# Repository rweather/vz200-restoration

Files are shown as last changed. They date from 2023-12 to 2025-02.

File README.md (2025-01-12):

VZ200 Restoration
=================

This repository chronicles my exploits in restoring a Dick Smith VZ200
that I got off eBay.  The VZ200 is a rebadged VTech Laser 200, which was
sold in Australia from 1983 onwards.

The eBay seller Ben had this to say about the unit: "It was an op-shop
pickup from my Nan and had been in storage in a plastic container for who
knows how long.  As it did not have any leads I never tested it."

## Technical specifications

* Z80A 8-bit CPU, running at 3.58MHz.
* 16K of ROM containing BASIC.
* 2K of video RAM for either 32 x 16 text mode or 128 x 64 graphics mode.
* 6K of user program RAM, expandable to 22K using a 16K RAM expansion module.
* 45 key chiclet keyboard organized in a 6x8 matrix.
* Motorola 6847 video processor.
* RF and composite video output.

Note: The VZ300 is essentially the same computer except that it has 16K of
user program RAM on-board and a mechanical keyboard.

Outside of Australia and New Zealand, the VZ200 and VZ300 were known as the
Laser 200 and Laser 310 respectively.

## Updates

Since doing the original restoration, I was gifted some more VZ200/VZ300
gear from a friend at work, Brian.  Brian got these years ago from an old
fellow in the local amateur radio network who was obviously a big fan of the
VZ computers, but was getting too old to work on them.

Many of the pieces have custom modifications and may or may not work.
Brian had 2 or 3 of everything.  He gave me these and kept the rest:

* Set of joysticks (working, just needed a clean).
* Printer interface.
* [16K memory expansion module that has been modified to 32K](Memory_Expansion_32K.md)
* Data casette recorder.
* Floppy disk controller and floppy disk drive.  Plus some floppy disks.
  Drive almost works but has a head crash; needs head re-alignment.
* Serial port kit.
* [Two VZ300's that were not working, but one now is.](VZ300_Restoration.md)

The links point at information about the restoration on each item.

Brian also gifted me a Microbee kit (assembled), two TRS-80 color computers,
and a TRS-80 printer/plotter.

I will gradually work on restoring these and post the results as I go.

And now onto the original restoration ...

## Restoration

Note: All images below have been scaled down.  Use "Open Image in New Tab"
or equivalent in your Web browser for a full-sized image.

### Initial condition of the unit

There were no power or video cables with the unit that was shipped to me.
The unit had not been powered on for a long time.  The power input is 9V DC
with a standard DC barrel jack, so power can be easily supplied with a
modern plugpack / wall wart.

The outside of the case was dirty, but nothing that some water, Windex,
paper towels, and elbow grease wouldn't fix.  The plastic was a little
yellowed but not too bad.

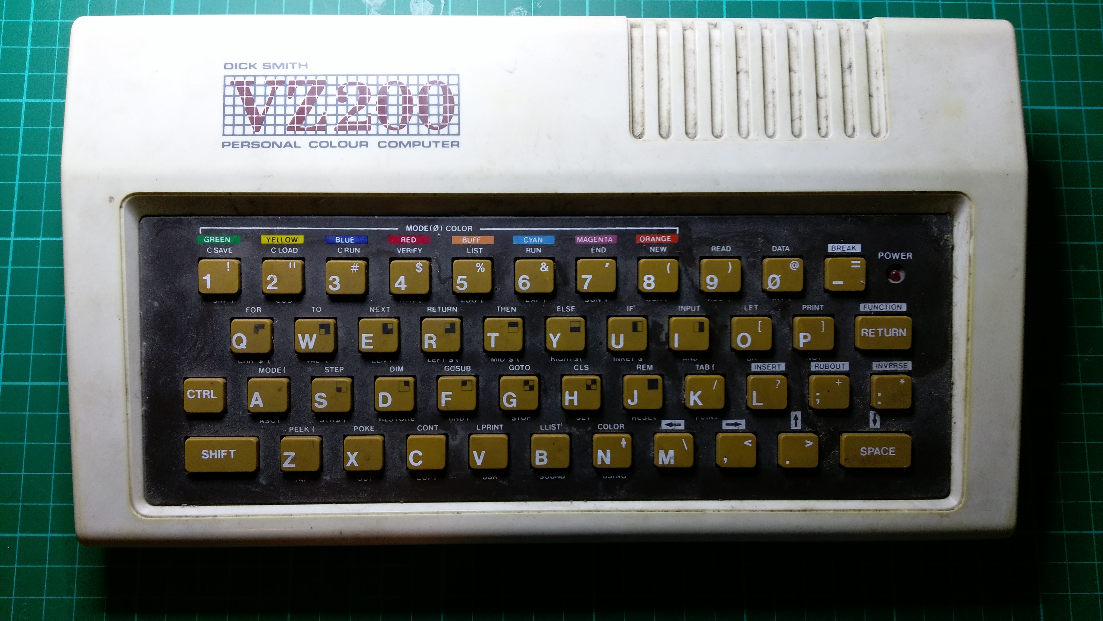
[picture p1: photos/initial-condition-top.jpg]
Initial Condition Top


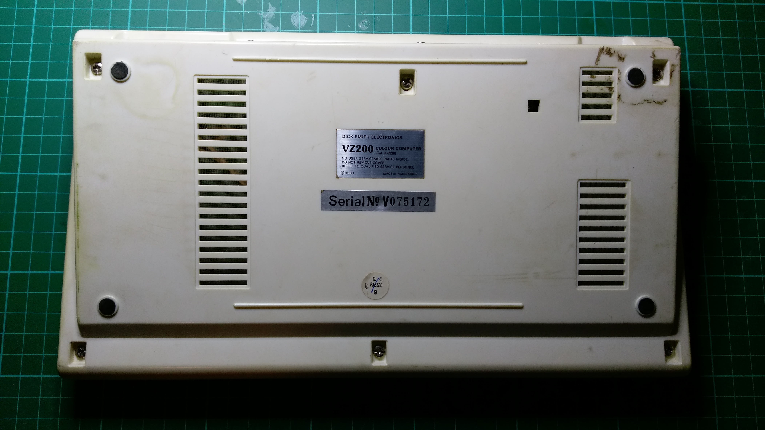
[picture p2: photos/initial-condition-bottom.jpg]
Initial Condition Bottom


Serial number 075172.

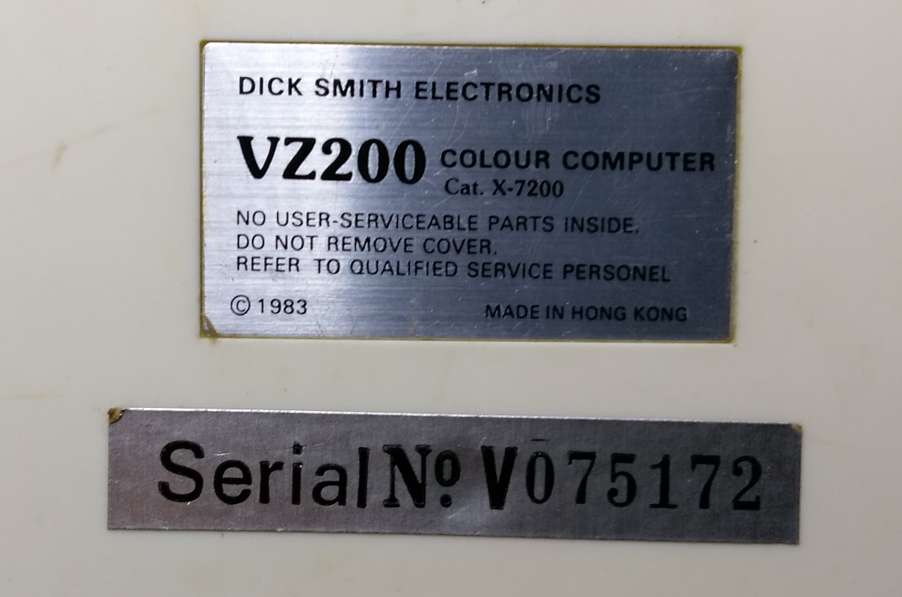
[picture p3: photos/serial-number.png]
Serial Number


The covers for the memory expansion and peripheral ports were still in place,
so I was hopeful that it had never been opened.

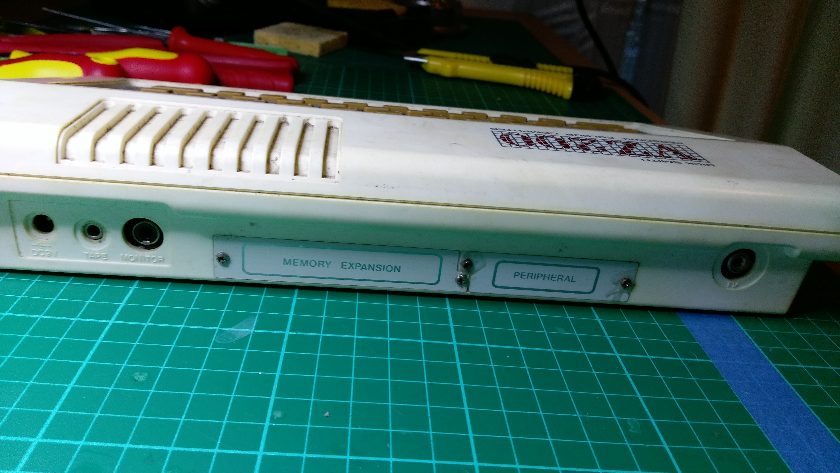
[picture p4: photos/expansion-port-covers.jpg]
Expansion Port Covers


However, once inside I discovered some dirt and the braids connecting the
RF shield to ground had been cut:

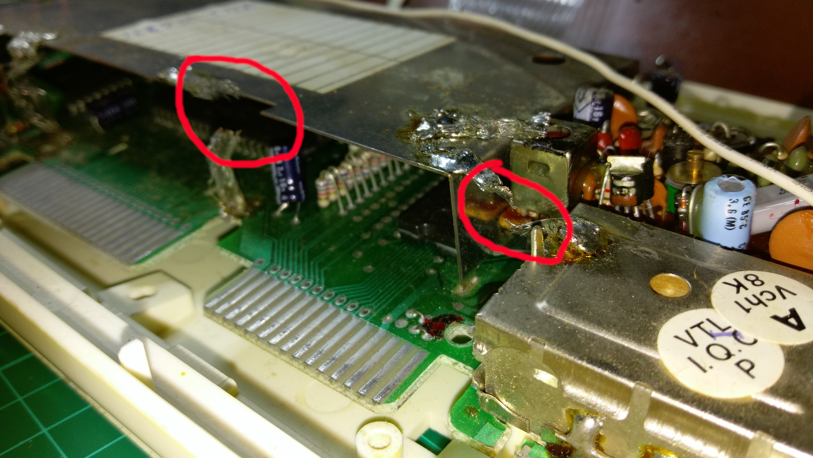
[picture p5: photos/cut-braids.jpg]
Cut Braids


It looks like someone had tried to remove the RF shield before and had
not succeeded.  The shield is soldered down to the motherboard, but some
of the legs were loose indicating partial success.

### Checking rail-to-rail resistance

I measured the resistance between 5V and ground - 284 ohms.  The same
between 9V and ground.  Probably OK.  Not a dead short anyway.

The resistance between 5V and 9V was 34 ohms, due to an actual 32 ohm
resistor between the two:

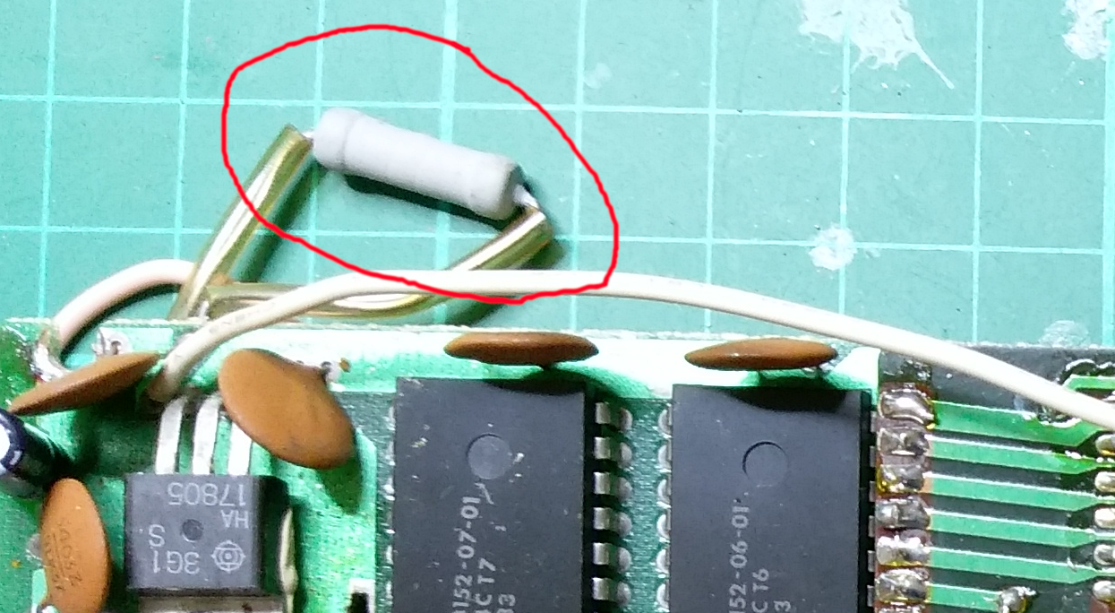
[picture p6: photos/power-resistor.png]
Power Resistor


### Removing the keyboard

I had to remove the keyboard from the top half of the case to clean the
case properly.  It looks like the original keyboard was in a module that
was pushed in from the top and then snapped into place.  Removing the
screws was easy, but I couldn't slide out the keyboard PCB without
cutting the snaps or the cross-piece.  I elected to cut the cross-piece:

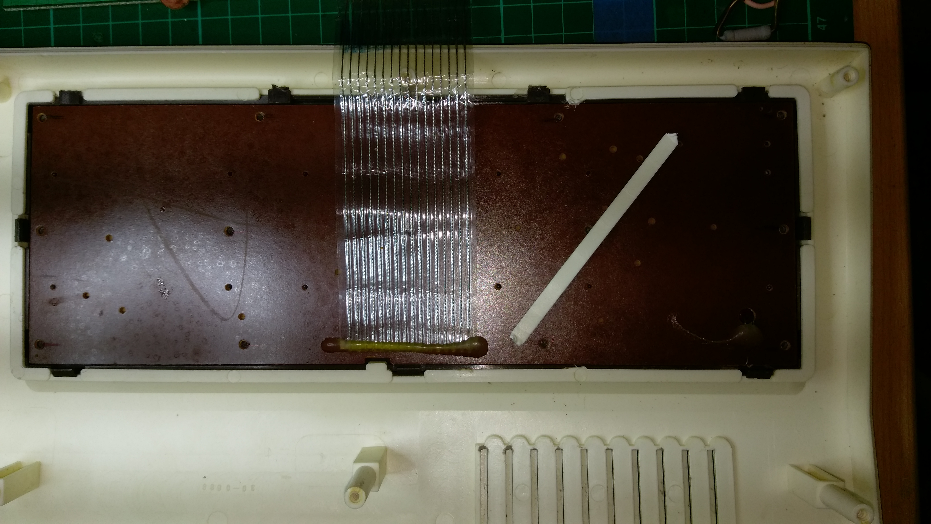
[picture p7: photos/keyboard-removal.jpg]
Keyboard Removal


The keyboard PCB has scratched-on letters indicating which key is which.
That's useful.

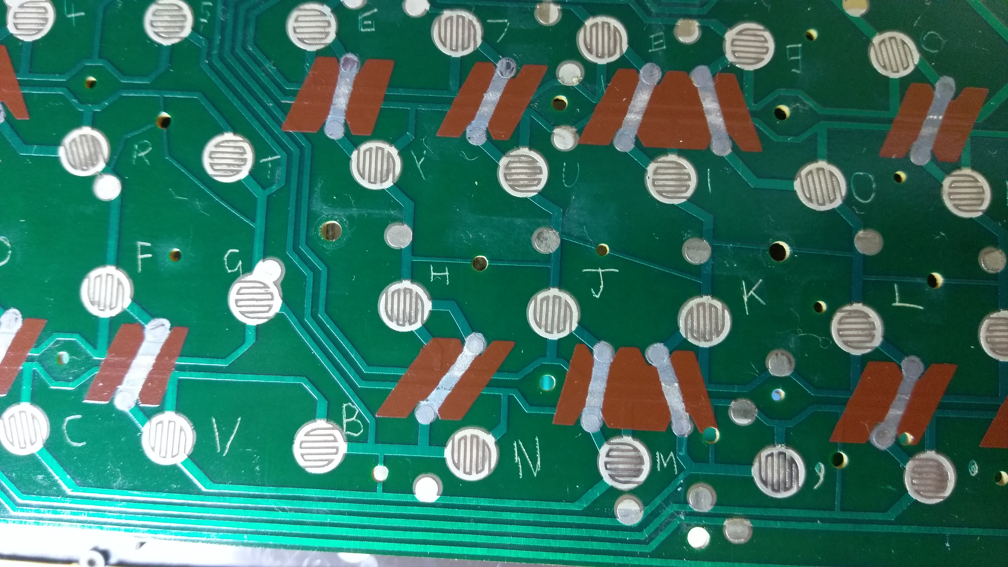
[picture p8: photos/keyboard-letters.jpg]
Keyboard Letters


After that, it was easy to remove the rubber membrane for cleaning.
The key caps themselves are molded into the membrane, so there are no
individual keys to get lost.  The membrane was filthy:

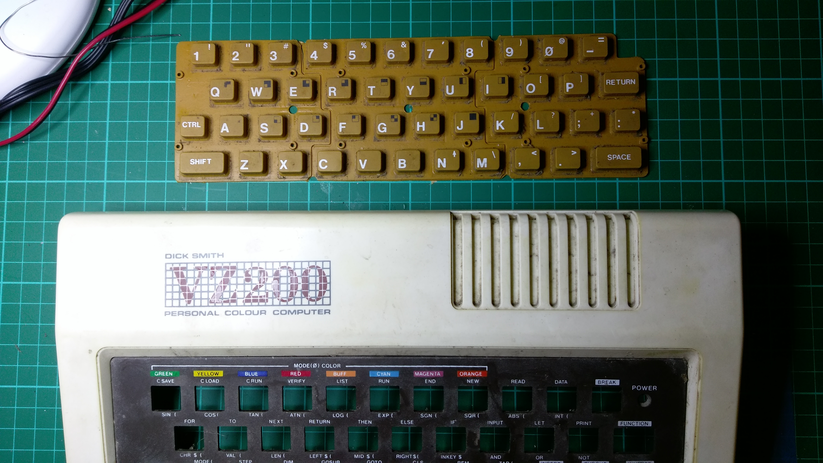
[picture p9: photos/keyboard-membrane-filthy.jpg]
Keyboard Membrane Before Cleaning


### Removing the RF shield

The person who tried to remove the RF shield didn't do a very good job.
Solder had bridged tracks, and one of the tracks was ripped right off the PCB:

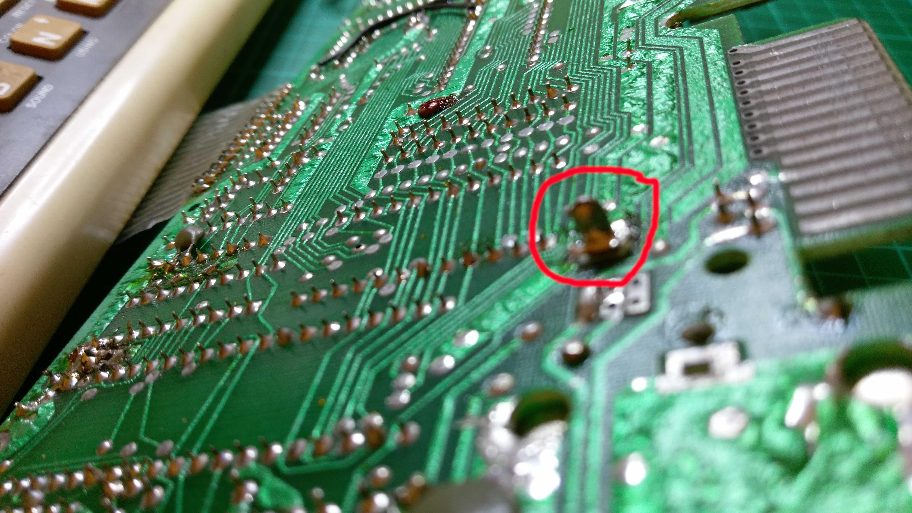
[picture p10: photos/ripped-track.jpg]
Ripped Track


Using a solder sucker, solder wick, flux, heat, and some patience,
I managed to clean up the excess solder and get the shield off:

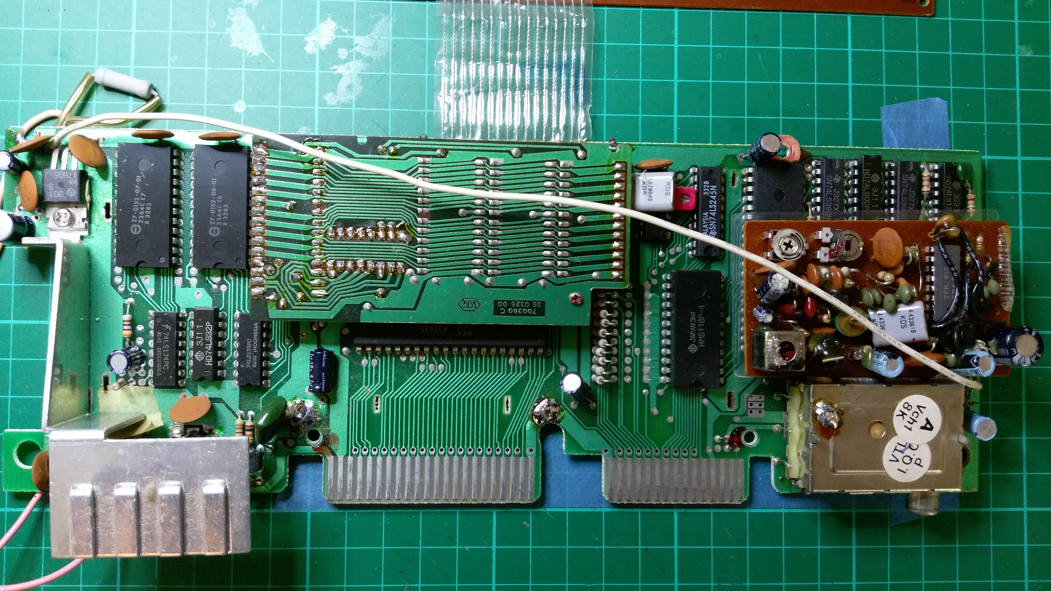
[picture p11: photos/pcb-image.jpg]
PCB Image


Here is the same photo with the major components marked up:

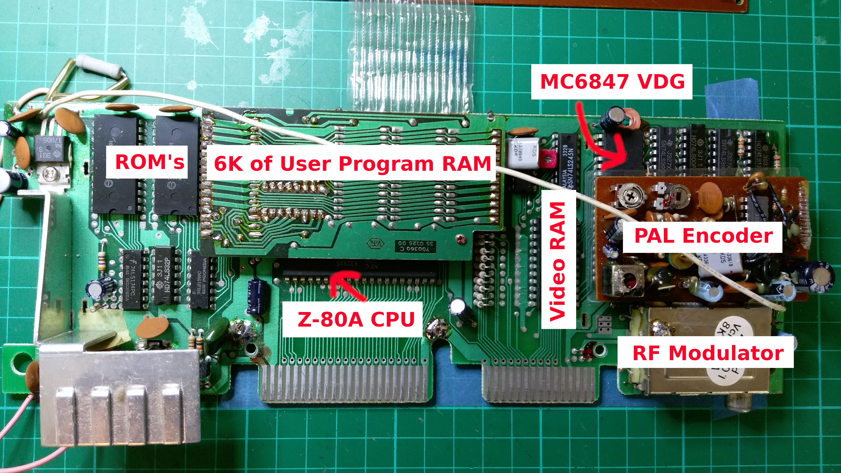
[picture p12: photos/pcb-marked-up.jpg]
PCB Image With Markings


And here is a diagram that shows the location of all IC's, looking forward
from the front of the PCB (not to scale):

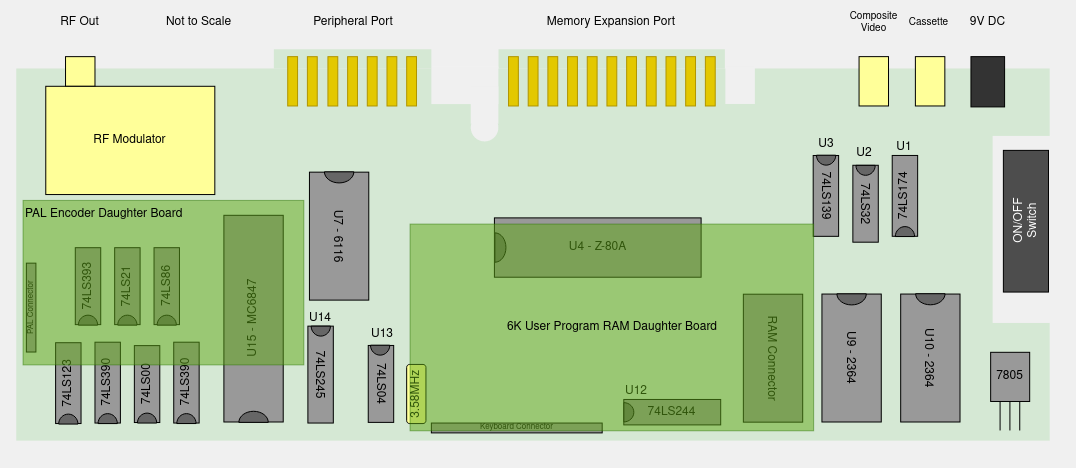
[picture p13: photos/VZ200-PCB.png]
PCB Layout


### Cleaning the case and keyboard membrane

I cleaned the top and bottom of the case and the keyboard membrane
with Windex and water.  Some stubborn stains on the back were cleaned
off with isopropyl alchohol.

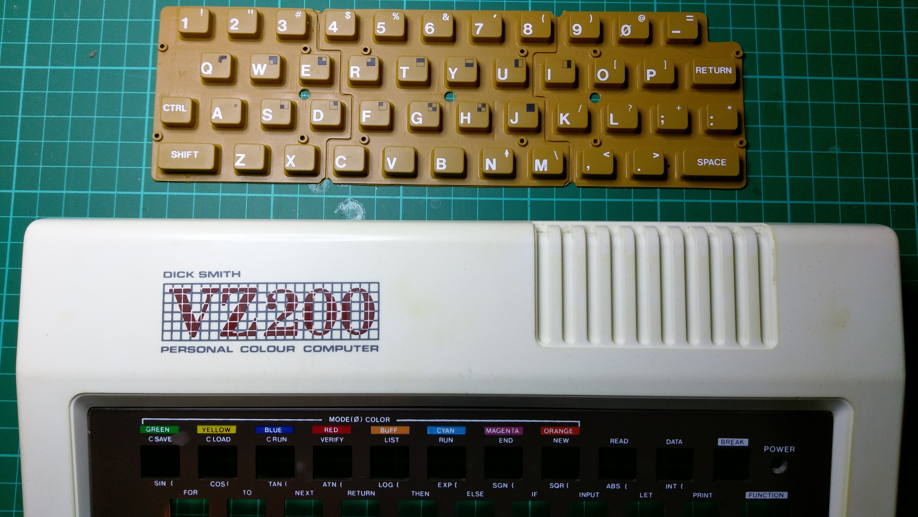
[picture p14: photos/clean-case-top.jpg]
Top and Keyboard Membrane After Cleaning


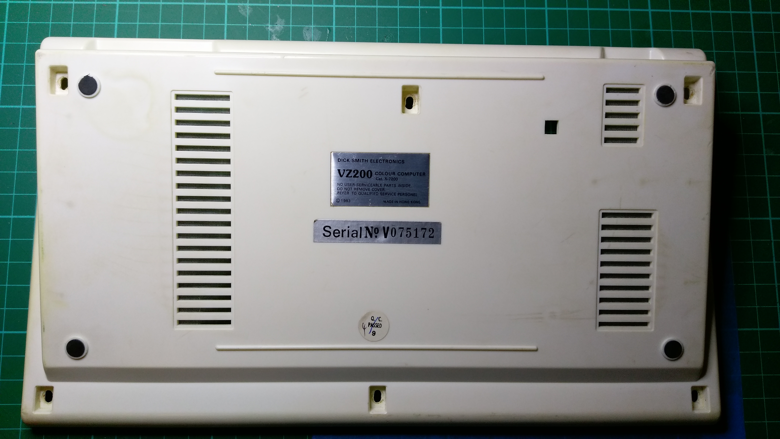
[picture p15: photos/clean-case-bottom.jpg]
Bottom After Cleaning


### First power on test

I connected a current-limited bench power supply set to 9V and 1A and
gingerly turned it on.  The 7805 voltage regulator was putting out 4.925V
and the system was consuming 650mA from the 9V supply.  So it looks like
no dead shorts on the board.

No blue smoke escaped, and the power LED turned on, so that's good.

### Checking signals

I checked the signals coming out of the CPU.  The clock on pin 6
was sitting at 3.57797MHz - close enough to 3.58MHz.

The address lines and most data lines had reasonable looking activity,
but D1, D2, and D6 had weird-looking signals like this for D6:

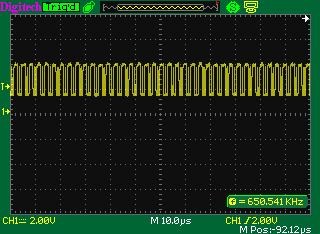
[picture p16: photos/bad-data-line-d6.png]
Bad D6 Line


The base line of the signal is shifted up by about 1.7V.  D1 and D2 were
also shifted to half-way between 0V and 5V.  So there was a conflict
on the data bus somewhere.

### Video test

Connecting up a Composite-to-HDMI video converter, I got garbage on
the screen.  Powering on and off multiple times gives different garbage
each time:

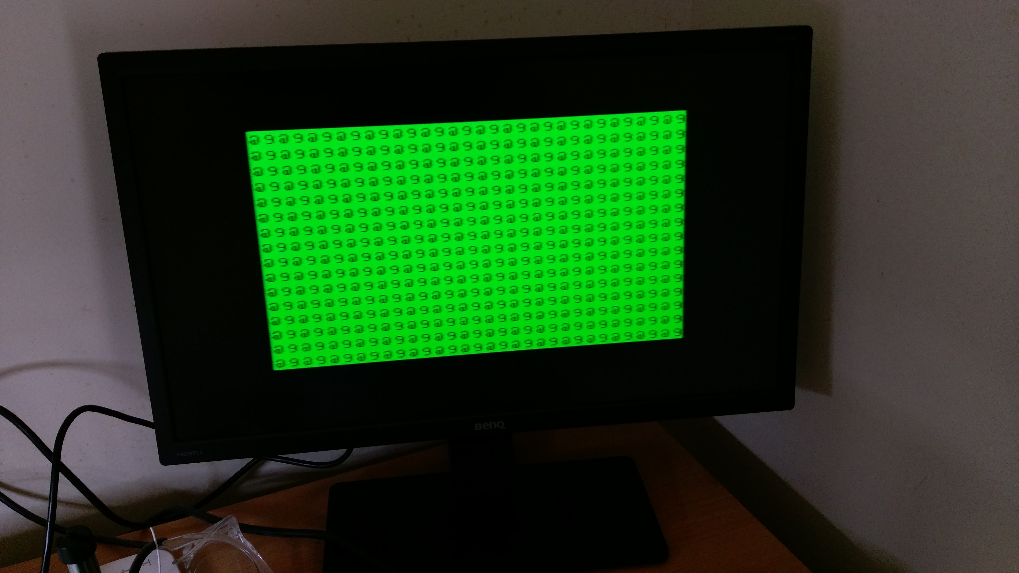
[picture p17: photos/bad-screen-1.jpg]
Bad Screen 1


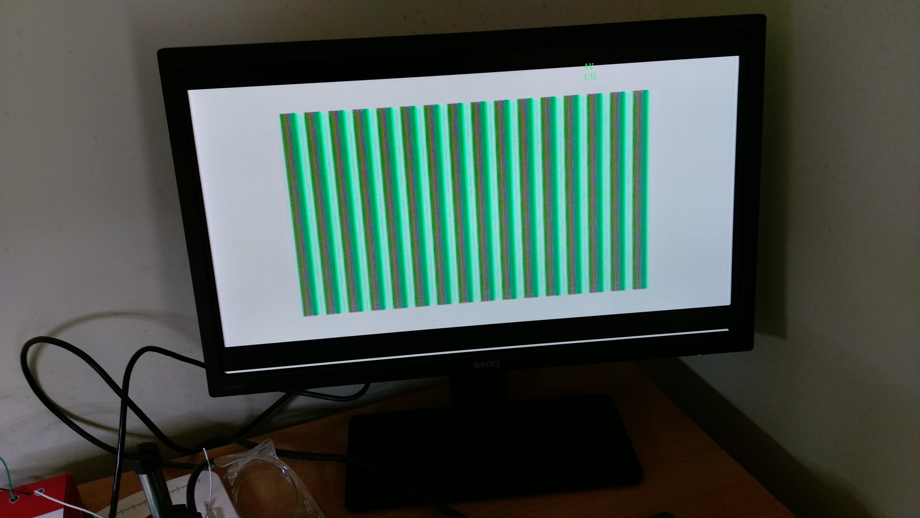
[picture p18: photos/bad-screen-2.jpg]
Bad Screen 2


The video clock into the MC6847 was around 3MHz, the "HS" horizontal sync
signal out was around 13kHz, and the "FS" frame sync signal out was 50Hz.

The video clock should be 3.58MHz.  However, the schematic gates the
main 3.58MHz system clock to generate the video clock.  "CLK" is the
main system clock:

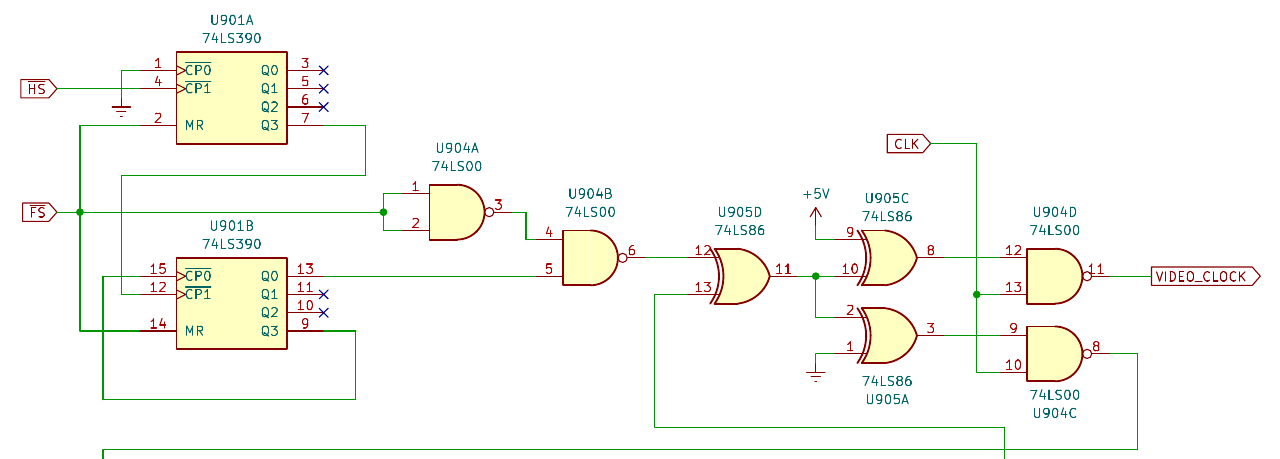
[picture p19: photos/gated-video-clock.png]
Gated Video Clock


In some parts of the frame during the horizontal and vertical sync times,
the video clock is disabled.  I think my oscilloscope was getting confused
and showing the average clock rate which undercounts due to the gating.
The same applies to the horizontal sync signal which isn't active for the
entire frame.

The frame sync was bang on 50Hz, and the generated video looked reasonable,
so the MC6847 must be getting the right timing.

The pictures don't show it, but there was a lot of static on the screen
which may be due to the clock signals, the CPU struggling to write to
video RAM, or a noisy component in the video output circuitry.

### Replacing the ROM's

From information I gleaned online, a common cause of bus crashes on the
VZ200 are the 2364 mask ROM's U9 and U10.  In [this video](https://www.youtube.com/watch?v=YIOjtE3j2aw)
from Tommy Ovesen at [Arctic Retro](https://www.arcticretro.com/),
he had similar screen corruption to my case.

Tommy replaced almost all the chips on the board before replacing the ROM's.
The ROM's were the ultimate culprit.  Rather than try replacing bus
transceivers, the CPU, or the video chip, I decided to learn from Tommy's
excellent work and start with the ROM's.

The wrinkle is that the original ROM's are 24-pin 2364's, but the best
replacements would be 28-pin 2764 EPROM's or (even better) AT28C64 EEPROM's.

It turns out that the PCB actually prefers 28-pin EPROM's!  There are
extra pin holes for the 28-pin footprint:

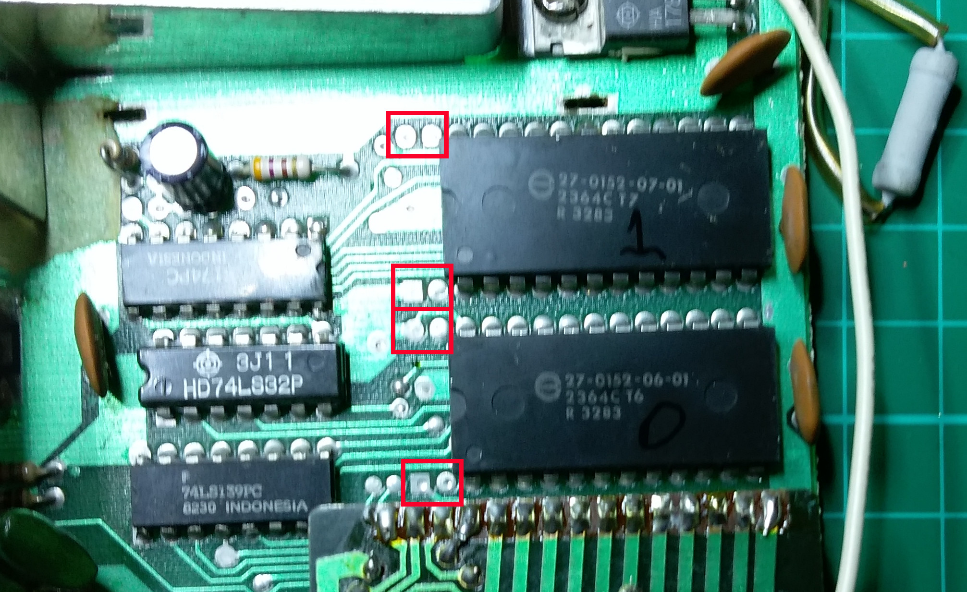
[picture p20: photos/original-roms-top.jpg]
Original ROM's Top


And on the back there are bodge wires to remap the 28-pin footprint into
24-pin so that the 2364's can be fitted:

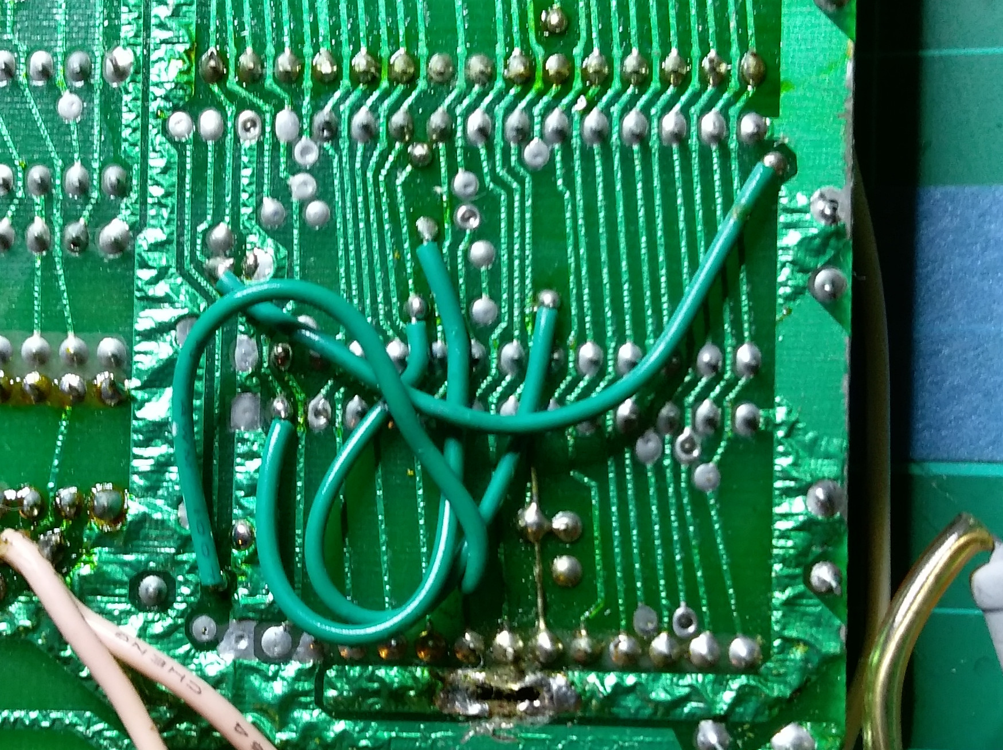
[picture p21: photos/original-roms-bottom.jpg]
Original ROM's Bottom


If we look at the original schematic in the
[VZ200 Technical Reference Manual](http://www.vz200.org/bushy/VZ200_technical_reference_manual.pdf), we can see that the footprint was supposed to be 28-pin:

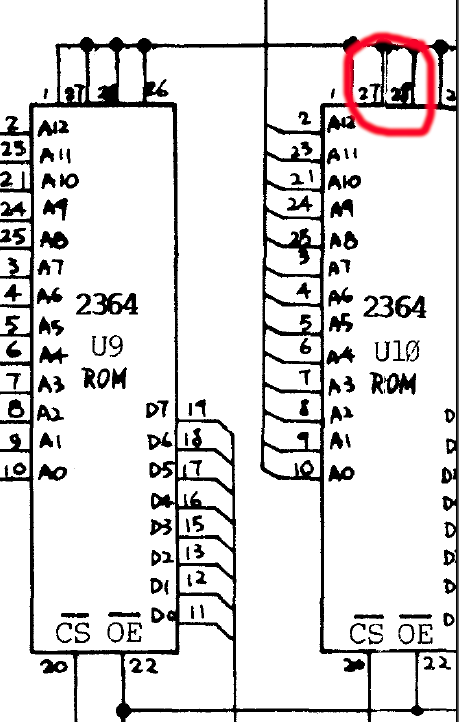
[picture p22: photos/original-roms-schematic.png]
ROM Schematic


My guess is that the manufacturer originally intended to use 28-pin
2764 EPROM's, but to save cost they went with 24-pin 2364's instead.
Apparently it was cheaper to pay people to modify thousands of PCB's
with bodge wires than to re-spin the PCB.

This was good for me.  I removed the ROM's and the bodge wires, and then
re-bodged the PCB back to the 28-pin footprint for the two AT28C64B-15PU
EEPROM's that I purchased from Mouser.  The following table shows the pin
mapping between the 24-pin and 28-pin footprints, with the major changes
shown in bold:

<table border="1">
<tr><td><b>2364 Pin</b></td><td><b>Connection</b></td><td><b>AT28C64 Pin</b></td><td><b>Connection</b></td></tr>
<tr><td> </td><td> </td><td><b>1</b></td><td><b>5V</b></td></tr>
<tr><td> </td><td> </td><td><b>2</b></td><td><b>A12</b></td></tr>
<tr><td>1</td><td>A7</td><td>3</td><td>A7</td></tr>
<tr><td>2</td><td>A6</td><td>4</td><td>A6</td></tr>
<tr><td>3</td><td>A5</td><td>5</td><td>A5</td></tr>
<tr><td>4</td><td>A4</td><td>6</td><td>A4</td></tr>
<tr><td>5</td><td>A3</td><td>7</td><td>A3</td></tr>
<tr><td>6</td><td>A2</td><td>8</td><td>A2</td></tr>
<tr><td>7</td><td>A1</td><td>9</td><td>A1</td></tr>
<tr><td>8</td><td>A0</td><td>10</td><td>A0</td></tr>
<tr><td>9</td><td>D0</td><td>11</td><td>D0</td></tr>
<tr><td>10</td><td>D1</td><td>12</td><td>D1</td></tr>
<tr><td>11</td><td>D2</td><td>13</td><td>D2</td></tr>
<tr><td>12</td><td>GND</td><td>14</td><td>GND</td></tr>
<tr><td>13</td><td>D3</td><td>15</td><td>D3</td></tr>
<tr><td>14</td><td>D4</td><td>16</td><td>D4</td></tr>
<tr><td>15</td><td>D5</td><td>17</td><td>D5</td></tr>
<tr><td>16</td><td>D6</td><td>18</td><td>D6</td></tr>
<tr><td>17</td><td>D7</td><td>19</td><td>D7</td></tr>
<tr><td><b>18</b></td><td><b>A11</b></td><td><b>20</b></td><td><b>CE</b></td></tr>
<tr><td>19</td><td>A10</td><td>21</td><td>A10</td></tr>
<tr><td><b>20</b></td><td><b>CE</b></td><td><b>22</b></td><td><b>RD</b></td></tr>
<tr><td><b>21</b></td><td><b>A12</b></td><td><b>23</b></td><td><b>A11</b></td></tr>
<tr><td>22</td><td>A9</td><td>24</td><td>A9</td></tr>
<tr><td>23</td><td>A8</td><td>25</td><td>A8</td></tr>
<tr><td>24</td><td>5V</td><td>26</td><td>5V</td></tr>
<tr><td> </td><td> </td><td><b>27</b></td><td><b>5V</b></td></tr>
<tr><td> </td><td> </td><td><b>28</b></td><td><b>5V</b></td></tr>
</table>

<b>Note:</b> The chip enable "CE" pins for the two ROM's are connected
to different pins on U3 / 74LS139.  CE on U9 / ROM0 should be connected
to pin 4 on U3.  CE on U10 / ROM1 should be connected to pin 5 on U3.
All other pins are connected identically on both ROM's.

Here is the PCB with the new ROM's fitted:

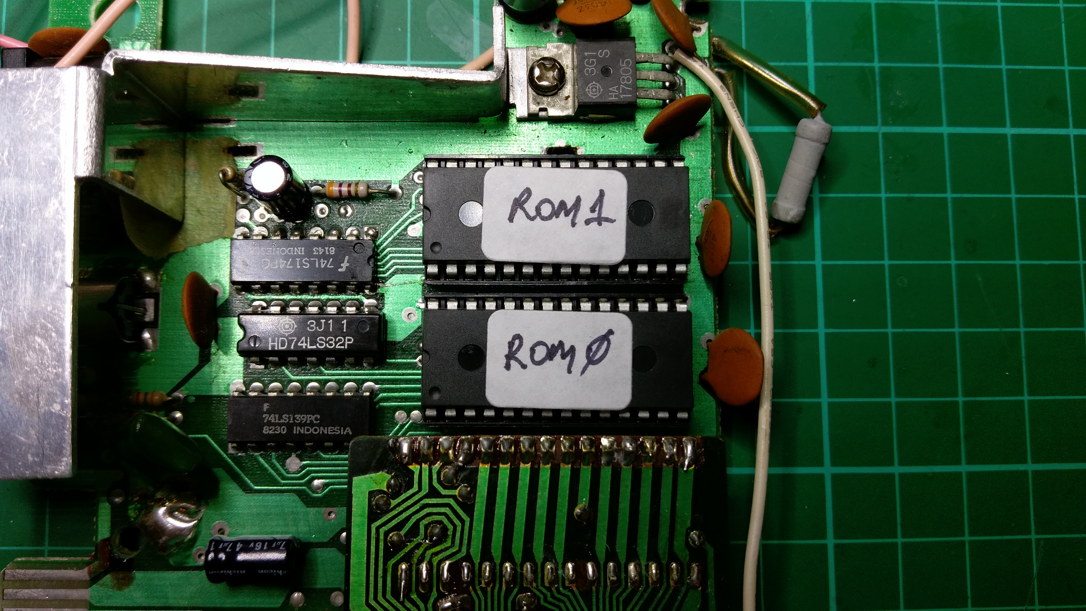
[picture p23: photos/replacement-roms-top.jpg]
Replacement ROM's Top


And here are the bodge wires I added on the back of the PCB:

Replacement ROM's Bottom

During the ROM removal process, I ripped up a few of the tracks so I have a
few more bodge wires than would be strictly necessary for the bold
alterations listed above.  Not my finest soldering job, but servicable.

The ROM images are available from Bushy's website.  Download the
"Everything" bundle from [here](http://www.vz200.org/bushy/software.html).
The ROM images are under "`ROMs/VZ ROM`" in the ZIP archive.  I used the files
`vtechv20.u09` and `vtechv20.u10`.

I used a TL866II Plus EEPROM Programmer and [minipro](https://gitlab.com/DavidGriffith/minipro) to flash the AT28C64B-15PU chips:

    <Put the first EEPROM in the programmer's socket>
    minipro -p AT28C64B -w vtechv20.u09

    <Put the second EEPROM in the programmer's socket>
    minipro -p AT28C64B -w vtechv20.u10

It is important to use the device name "AT28C64B" instead of "AT28C64"
with minipro.  The device name without the "B" didn't work.

With the 28-pin modifications above, it should be possible to fit
AT28C128 (16K) or AT28C256 (32K) instead of AT28C64 (8K).
The high address lines will be pulled high, so you will need to
flash the images into the top-most 8K of the replacement EEPROM's.
You will still need two EEPROM's, even if they are 16K or 32K in size,
because of how address decoding works on the PCB.

### Testing

After replacing the ROM's, I hooked up the power and composite video output
and turned the computer on.  This happened:

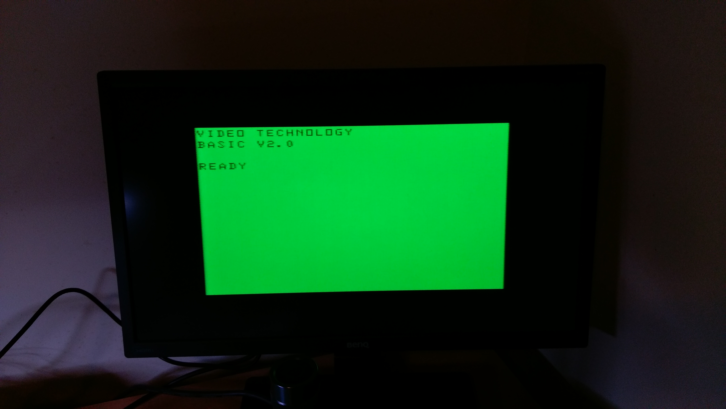
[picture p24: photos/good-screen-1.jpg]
Good Screen 1


Yay!  It works!  The text is correct, the cursor blinks, and there is no
static on the screen.  So replacing the ROM's did the trick.

The current draw of the unit was originally 650mA on the 9V input.
After replacing the ROM's, the current draw is now 550mA.

### Keyboard ribbon cable

After repeated handling of the PCB while replacing the ROM's, the soldered-on
keyboard ribbon cable eventually tore off the PCB.  So I replaced it with a
proper connector setup using 2.54mm pin headers and sockets:

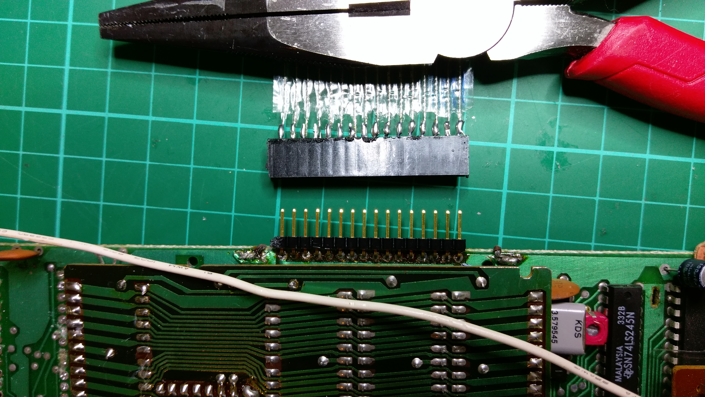
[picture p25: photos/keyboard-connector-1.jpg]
Keyboard Connector 1


There is more than enough room in the case for the connector, so there
weren't any clearance issues:

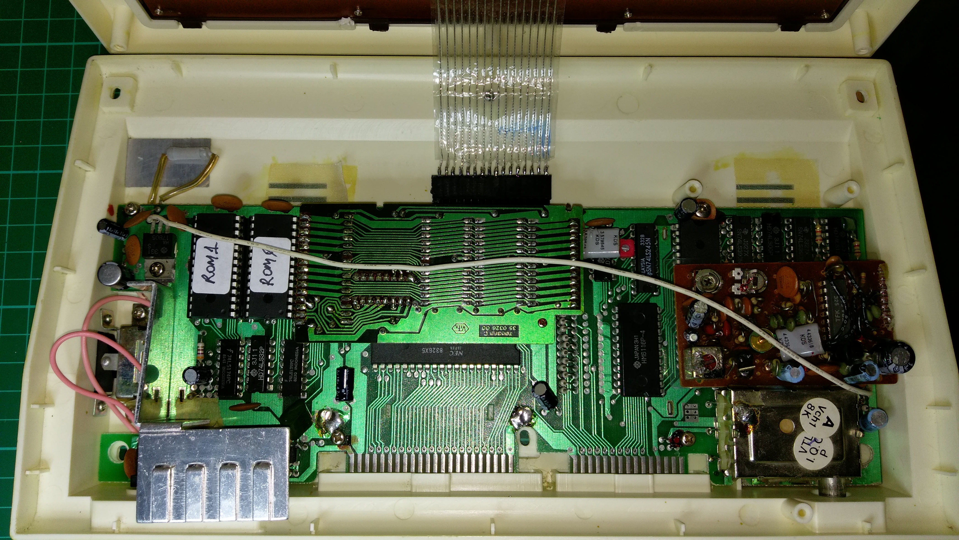
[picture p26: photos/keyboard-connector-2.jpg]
Keyboard Connector 2


After connecting the keyboard, I tried writing a little BASIC program:

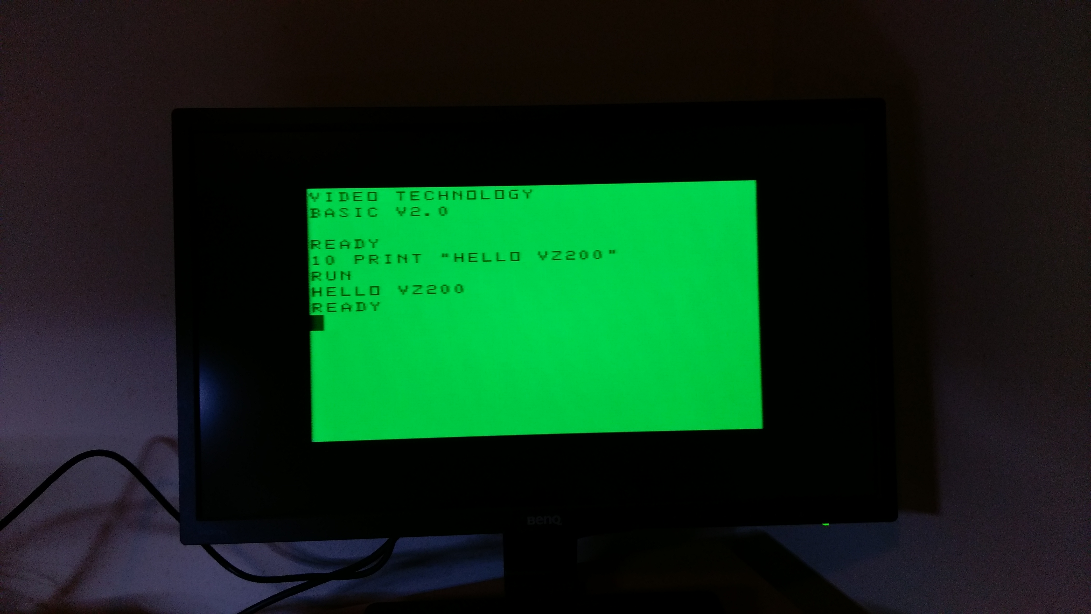
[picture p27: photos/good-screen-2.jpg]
Good Screen 2


All of the keys work reliably except CTRL.  Sometimes it works, but not always.
May be an alignment issue or something wrong with the membrane under the key.

### Fixing the CTRL key

I disassembled the keyboard again and carefully scrubbed the contacts on the
PCB and the membrane itself with dry cotton buds.  There was still a little
dirt in the membrane and on the contacts.

Previously I tightened the keyboard screws quite tight when I reassembled
the keyboard.  One theory I had was that the membrane didn't have enough
"play" because it was too tight / stretched around the CTRL key.
When I reassembled the keyboard I screwed in the screws until they
stopped moving.  But I didn't tighten any further than that.

Whether it was the cleaning or the untightened screws, the CTRL key now works.

### Conclusion

Here is a summary of the changes that I made:

* Clean the case and keyboard membrane.
* Remove the RF shield.
* Replace the 24-pin 2364 mask ROM's with 28-pin AT28C64B-15PU EEPROM's.
* Modify bodge wires around the ROM's to support the 28-pin footprint.
* Upgrade the ROM's to version 2.0.
* Remove the cross-piece in the case top to access the keyboard for cleaning.
* Replace the soldered keyboard ribbon cable with a proper connector.

Costings:

* USD$12 for the two replacement AT28C64B-15PU EEPROM's ($6 each).
* USD$2 for two 28-pin DIP sockets.
* USD$20 for a 9V DC plugpack / wall wart.
* Two weeks of nights and weekends for the full restoration.

And here it is in all of its restored glory:

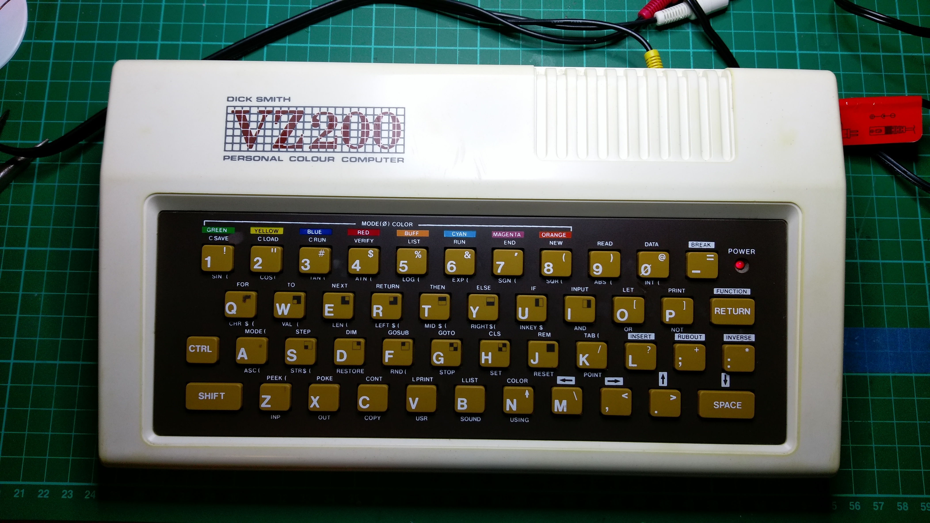
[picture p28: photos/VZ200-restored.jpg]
Final Restored Condition


## Schematics

I have reproduced the schematics from the VZ200 and VZ300 Technical
Reference Manuals in KiCad and generated PDF versions.  The original
schematics can be hard to read.

* [VZ200 Motherboard](schematics/VZ200/PDF/VZ200.pdf)
* [VZ300 Motherboard](schematics/VZ300/PDF/VZ300.pdf)
* [Printer Interface](schematics/VZ200_Printer_Interface/PDF/VZ200_Printer_Interface.pdf)
* [16K Memory Expansion Module](schematics/VZ200_16K_RAM_Expansion/PDF/VZ200_16K_RAM_Expansion.pdf)
* [Joystick Interface](schematics/VZ200_Joystick_Interface/PDF/VZ200_Joystick_Interface.pdf)

Note: The VZ200 motherboard schematic includes components for the PAL encoder
and 6K of Program RAM that were on separate PCB's in the original design.

There is a lot of missing detail in the manual.  Many of the components do
not have designators, so there is no way to know if a resistor was originally
R1, R63, or R128.  The PCB does not have a silkscreen marking the components.
In some cases, the component value is not provided.

For components without a designator, I made up numbers starting at 900;
e.g. R906, C912, U904, etc.  For components without a known value, I listed
the value as "???".  I was able to determine some of the values by inspecting
the actual PCB.

## Adapting the schematic

In theory the KiCad schematic could be modernised and then laid out on a
brand new PCB.  But a lot of work would be required to add footprints
and lay everything out.  Some of the components are pretty ancient
and would need modern replacements.

It would be nice to be able to build a brand new VZ200 from modern components.
I haven't attempted to do this, but others are welcome to try using my
schematic as a starting point.  Here is a list of things to fix:

* Replace the 6K of program RAM plus the 16K memory expansion module with a
single 32K static RAM chip on-board like the 62256.  Provide a switch for
6K operation for use with third-party expansion modules that provide
their own RAM.
* The 2K of video memory is on a separate data and address bus,
so it will probably need special handling.
* To avoid screen flicker, double the main system clock from 3.58MHz to
7.16MHz and use alternating clock pulses for the CPU and MC6847 to avoid
bus contention.
* Replace the two 8K mask ROM's with a modern 16K or 32K EEPROM.
* The MC6847 Video Display Generator (VDG) has additional graphics modes
that were not accessible with the original design.  Some people have
already modified their VZ200's to access these modes.
* The chiclet keyboard is horrible, but a lot of software depends upon
the specific arrangement of buttons in the key matrix.  Consider replacing
with mechanical key switches like on the VZ300, but the same matrix
arrangement.
* As an alternative keyboard approach, use a microcontroller to convert the
signals from a standard USB keyboard into the key matrix signals.
* If you have FPGA skills, then consider replacing the MC6847 with an
alternative that puts out standard RGB or HDMI video instead of
composite video.  This would greatly simplify the video output circuitry.
* The original schematic in the technical reference manual did not have
100nF filter capacitors on the major chips.  The actual PCB does have a
small number of 40nF capacitors and some electrolytics scattered around
that were not listed in the original schematic.  I have captured some of
them in my schematic.  Ensure that the voltage rails are properly filtered.
* U13 is a 74LS04 hex inverter with a spare inverter gate, but the input
was not tied to ground or 5V.  There is also a spare XOR gate in the
16K memory expansion module whose inputs aren't tied high or low either.

## Other documentation

* [VZ200 startup sequence](doc/startup-sequence.md)
* [Useful Memory Locations](doc/useful-locations.md)

## Resources

* [Wikipedia article](https://en.wikipedia.org/wiki/VTech_Laser_200)
* [vz200.org](http://vz200.org/)
* [Bushy's VZ200 website](http://www.vz200.org/bushy/)
* [VZ200 Technical Reference Manual](http://www.vz200.org/bushy/VZ200_technical_reference_manual.pdf) from Bushy's website.
* [VZ300 Technical Reference Manual](http://www.vz200.org/bushy/VZ300_tech_manual.pdf) from Bushy's website.

## Acknowledgements

I was inspired to try my hand at restoring a vintage 1980's computer by the
following YouTubers:

* [Adrian's Digital Basement](https://www.youtube.com/@adriansdigitalbasement)
* [Artic Retro](https://www.youtube.com/@Arcticretro)
* [Noel's Retro Lab](https://www.youtube.com/@NoelsRetroLab)
* [The 8-Bit Guy](https://www.youtube.com/@The8BitGuy)
* [Usagi Electric](https://www.youtube.com/@UsagiElectric)

Artic Retro in particular is an expert in VZ200 / Laser 200 computers.

Thanks for sharing the enthusiam and teaching me so much!

## History

My first computer was a Dick Smith Cat, which was a rebadged Laser 3000.
Mine died a long time ago and I sent it to the dump.  I now wish I hadn't!

I thought that the VZ200 I found on eBay would be the closest I would
ever come to my beloved Cat - it is a similar vintage.  However as of
July 2024, I now have a Cat again after purchasing one on Gumtree.  Yay!

I am also looking for the following to complete my set of early 1980's
Australian computers.  Some of which I have since found:

* Dick Smith Sorcerer (found May 2024)
* Dick Smith System 80 (TRS-80 clone) (found January 2025)
* Dick Smith Super 80 (this was a kit made in concert with Electronics Australia)
* Microbee (found Jan 2024)
* Electronics Australia or ETI kit computers like DREAM-6800, ETI-660, or EDUC-8

Other restoration information of mine on github:

* [Kit Microbee](https://github.com/rweather/microbee-restoration)
* [Dick Smith Cat](https://github.com/rweather/cat-technical-information)
* [Dick Smith System 80](https://github.com/rweather/system80-restoration)

## License

<p xmlns:cc="http://creativecommons.org/ns#" xmlns:dct="http://purl.org/dc/terms/"><span property="dct:title">VZ200 Restoration</span> by <span property="cc:attributionName">Rhys Weatherley</span> is licensed under <a href="http://creativecommons.org/licenses/by-nc-sa/4.0/?ref=chooser-v1" target="_blank" rel="license noopener noreferrer" style="display:inline-block;">Attribution-NonCommercial-ShareAlike 4.0 International</a></p>

## Contact

For more information on this project, to report bugs, or to suggest
improvements, please contact the author Rhys Weatherley via
[email](mailto:rhys.weatherley@gmail.com).

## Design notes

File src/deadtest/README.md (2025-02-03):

VZ200/VZ300 Dead Test
=====================

This directory contains a "Dead Test" ROM image for VZ200 and VZ300
computers.  It assumes that ROM address decoding, the MC6847 Video
Display Generator (VDG), and the 2K of static video RAM are basically
working, but everything else will be tested by the ROM as it executes.

To use it with VZ200, replace U9 (ROM0) with the 8K dead test image.
To use it with VZ300, replace U12 with the 16K dead test image.
Obviously, you will need to desolder the original ROM's and fit a
socket for the replacement EEPROM.

8K, 16K, and 32K versions of the image are provided, depending upon what
size of EEPROM you are using.  The 16K and 32K versions duplicate the
8K image multiple times so that the test can run from any 8K-aligned address.

Here is what a successful result looks like on a VZ200:

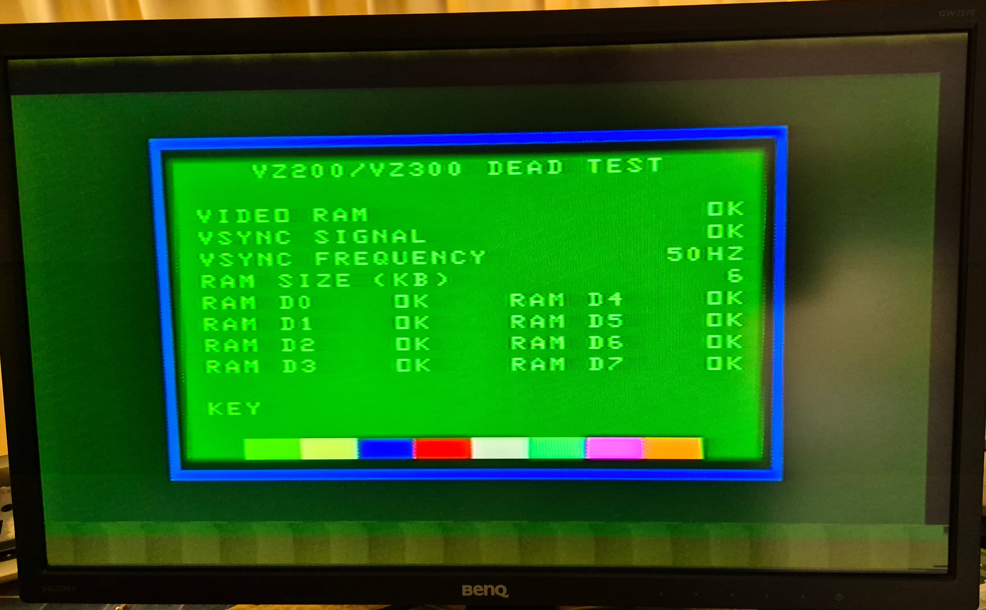
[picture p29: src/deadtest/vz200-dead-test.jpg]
VZ200 Dead Test Result


## Building

The assembly code in `deadtest.asm` is designed to be assembled by
[pasmo](https://pasmo.speccy.org/) under a Linux-like system.  It is assumed
that pasmo has been installed and is somewhere on your PATH.  Then type:

    make

This will build `vzdt8k.rom`, `vzdt16k.rom`, and `vzdt32k.rom`.

## Tests

### Video Display

Display of video is tested implicitly.  If you see readable text on the
screen, then the MC6847 Video Display Generator (VDG) and the video
output circuitry are working.  Also, the Z80 CPU is successfully running
code out of ROM.

### Beep

The dead test will beep the speaker at startup.  If you don't see
readable text on-screen but hear the beep, then the Z80 CPU is
successfully running code out of ROM but there may be something
wrong with the video system.

If you see readable text on-screen but don't hear a beep, then either the
speaker is not connected or there is something wrong with I/O output:
U1 (74LS174), U2 (74LS32), and U3 (74LS139) on the VZ200.  On the VZ300,
I/O output is handled by a combination of U13 (Gate Array 1) and
U14 (Gate Array 2) - mostly U14.

### Video RAM

Fills the 2K of video memory at $7000 with a test pattern and reads it back.
Test succeeds if the contents are the same.  This tests U7 on the VZ200 or
U16 on the VZ300.

This will verify that address decoding of the range $7000 to $77FF is working,
which is a combination of U2 (74LS32), U3 (74LS139), and U14 (74LS245)
on the VZ200.

On the VZ300, a combination of U13 (Gate Array 1) and U14 (Gate Array 2)
are involved in video RAM access.  If you see something on-screen and
you hear a beep, then these chips are probably OK.

If the video RAM test fails, then the test will fill the screen with the
character set twice: forwards in the top half of the screen and backwards
in the bottom half of the screen.  It will also write "VRAM BAD" in the
top-left corner.  After that it will flash the background color between
green and orange while beeping the speaker.  No other tests are possible.

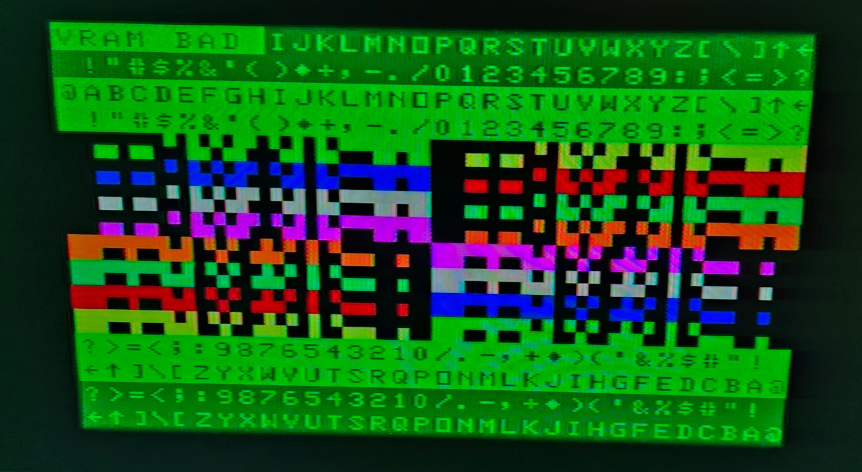
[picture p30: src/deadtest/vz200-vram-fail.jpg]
VZ200 VRAM Fail


### VSYNC

The vertical sync signal from the MC6847 is delivered to the CPU on the
"INT" interrupt pin, and also via the I/O input interface.  Under normal
operation a 50Hz or 60Hz active-low pulse is expected on this signal.

The first part of this test polls the I/O input to look for regular pulses.
If no pulses are seen, then "BAD" is reported and the second part of the
test is skipped.

If the first part succeeds, then interrupts will be enabled and the test
repeated.  The number of interrupts per second is measured and the test will
report "50HZ", "60HZ", or "??HZ" as appropriate.

The interrupt test is the first test that needs working RAM for the
stack and the interrupt counter.  If video RAM is not actually working
despite the previous tests, then the dead test may get stuck here.

### Main Program RAM

This test determines how much main program RAM is present on the system,
and tries to figure out which data bits are not working correctly.

On the VZ300 which uses dynamic RAM, this can help identify dead DRAM chips.
It is also possible that U10 (Gate Array 3) is dead, as it is responsible
for DRAM access.  If all data bits report as bad, then check the
address and CAS lines with an oscilloscope to see if they are stuck.
If they are, then the gate array is probably the culprit.

On the VZ200, things are simpler.  Pull the static RAM chips and test them.
The 74LS138 address decoder may also have issues.

### Keyboard

After all previous tests, the dead test will go into an infinite loop
waiting for keys to be pressed on the keyboard.  The keys that are
pressed will be displayed on-screen; e.g. `SHIFT+B`.

This tests the keyboard and I/O input.  On the VZ200, U2 (74LS32),
U3 (74LS139), and U12 (74LS244) are involved in keyboard input.  On the VZ300,
a combination of U13 (Gate Array 1) and U14 (Gate Array 2) are involved in
keyboard input - mostly U14.

If some of the keys are working, then check which ones fail against the
key matrix:

    Address   | D5  D4  D3  D2  D1  D0
    ----------+-----------------------
    $68FE  A0 |  R   Q   E       W   T
    $68FD  A1 |  F   A   D CTRL  S   G
    $68FB  A2 |  V   Z   C SHFT  X   B
    $68F7  A3 |  4   1   3       2   5
    $68EF  A4 |  M  SPC  ,       .   N
    $68DF  A5 |  7   0   8   -   9   6
    $68BF  A6 |  U   P   I RETN  O   Y
    $687F  A7 |  J   ;   K   :   L   H

If all of the keys in a row are dead, then that address line may have a
problem.  If all of the keys in a column are dead, then that data line
may have a problem.  Check the tracks around the keyboard connector on
the PCB and the keyboard ribbon cable for breaks.

Press CTRL+BREAK to restart the test sequence from the beginning.

## Cartridge Version?

To run the dead test it is necessary to desolder a ROM chip from the
motherboard and replace it (after adding a socket of course).  In theory,
the dead test could be made into a cartridge that plugs into the
expansion port instead.  No de-soldering required.

In the VZ200/VZ300 design, the cartridge ROM code is only executed after a
lot of regular ROM initialisation and RAM access have already occurred.
If these are bad, then the cartridge ROM code will never be executed.
This defeats the purpose of the dead test.

This is unlike the Commodore 64 and other platforms where inserting a
cartridge physically disables the main ROM.  On those platforms, the
dead test can be non-invasive.

## Updates

3 February 2025: Adrian Black from [Adrian's Digital Basement](https://adriansbasement.com/)
found a bug with my dead test while repairing a Laser 200.  Devices with 34K
of RAM reported as "@@" because I skipped the "33" between the "32" and "34"
in the RAM size table.  Adrian had some other suggestions as to how to
better report VRAM failure, which I also implemented (see above).

## Contact

For more information on this project, to report bugs, or to suggest
improvements, please contact the author Rhys Weatherley via
[email](mailto:rhys.weatherley@gmail.com).

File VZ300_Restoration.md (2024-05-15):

VZ300 Restoration
=================

My friend Brian had two VZ200's and two VZ300's in his shed.  One each of the
VZ200's and VZ300's were working, so he kept them and gave me the two
non-working ones.

* [VZ300 Schematic](schematics/VZ300/PDF/VZ300.pdf)

## Unit 1

The first unit was a plain VZ300 with a mechanical keyboard:

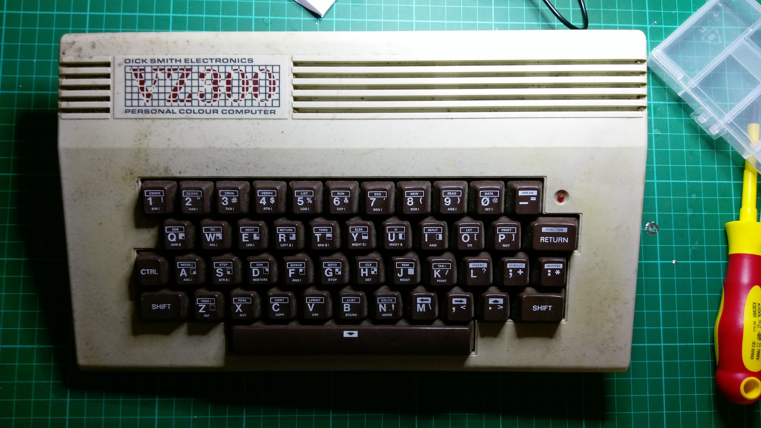
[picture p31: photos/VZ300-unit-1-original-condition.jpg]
VZ300 Unit 1 Original Condition


The RF shield had been removed, but the PCB appeared to be in good condition:

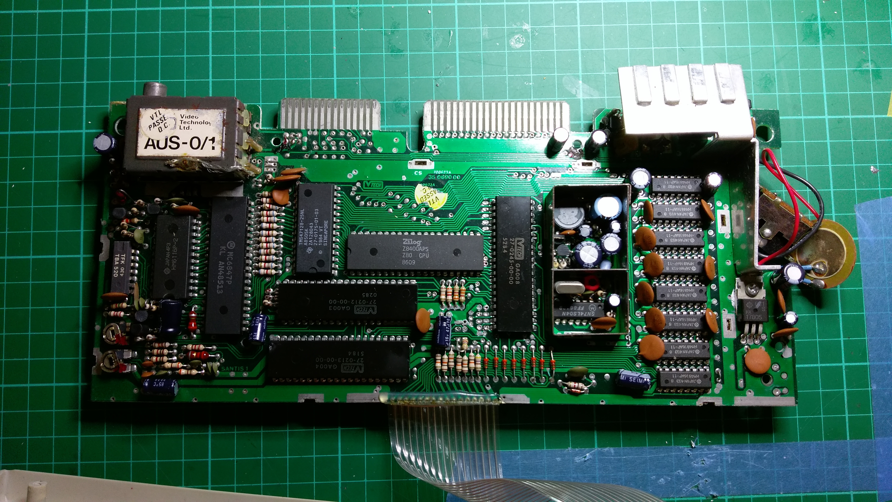
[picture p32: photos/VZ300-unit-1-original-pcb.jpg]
VZ300 Unit 1 Original PCB


However, when I powered it on the screen showed garbage.  The data and
address lines looked OK, although the ROM chip select looked a little wonky.
I put unit 1 aside - see below for when I revisited Unit 1 later.

## Unit 2

The "VZ200" that Brian gave me was actually a VZ300 in a VZ200 case!

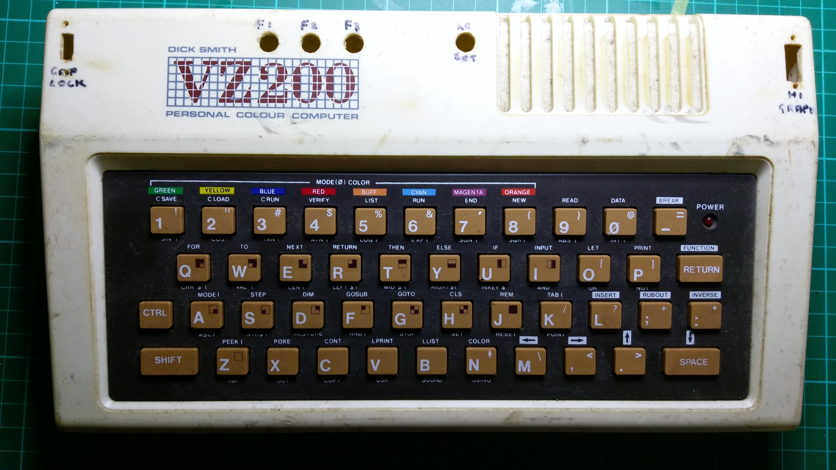
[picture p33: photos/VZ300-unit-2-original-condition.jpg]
VZ300 Unit 2 Original Condition


The RF shield was still fitted, but the keyboard ribbon cable and
piezospeaker wires had been cut:

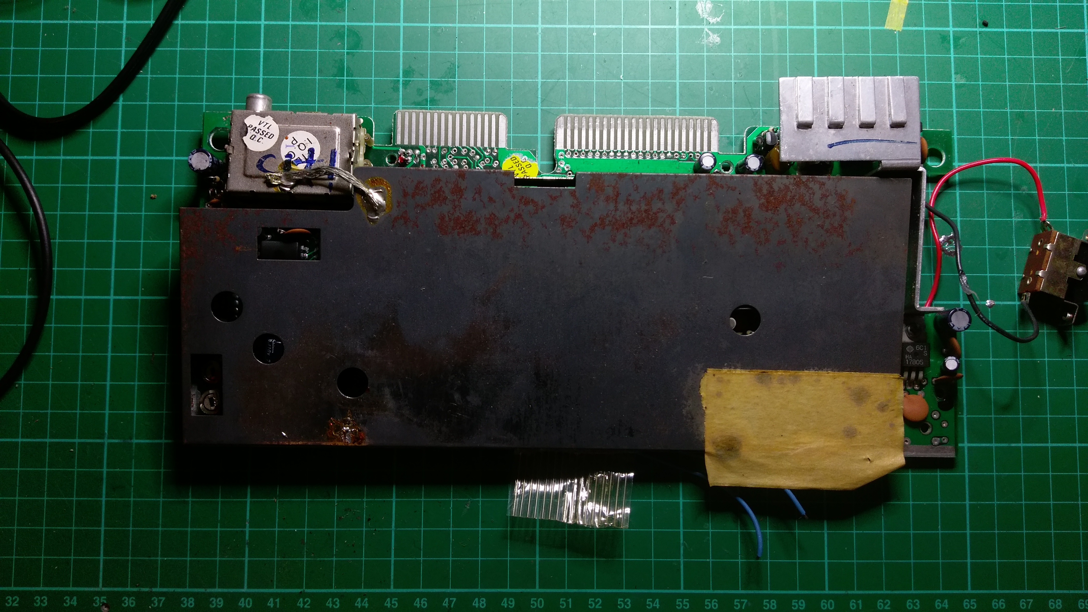
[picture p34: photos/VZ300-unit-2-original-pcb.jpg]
VZ300 Unit 2 Original PCB


Why was it in a VZ200 case?  Well, the original owner prior to Brian had
swapped the VZ200 and VZ300 motherboards for two of his units.  This gave
him a VZ200 with a mechanical keyboard!  Brian still has the "VZ200 in a
VZ300 case".  The Unit 2 VZ300 is the left-over PCB that was never
reconnected in its new case.

The VZ200 case also has some interesting modifications:

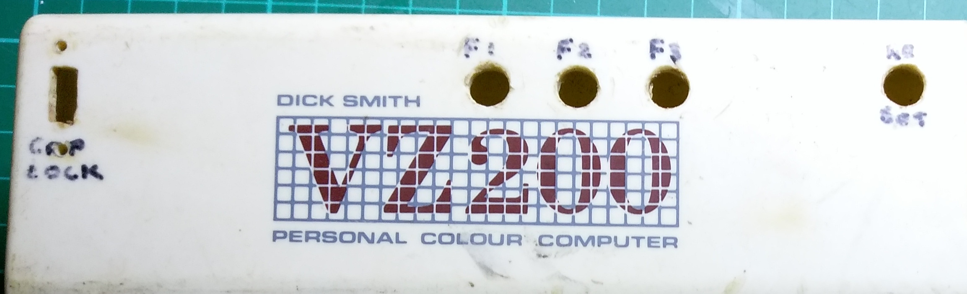
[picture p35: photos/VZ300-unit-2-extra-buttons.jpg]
VZ300 Unit 2 Extra Buttons


The original owner had added extra function keys, a caps lock key, and a reset
button to the keyboard matrix.  These holes are where the extra keys were
located.  The "VZ200 in a VZ300 case" has similar modifications
(this picture is a screenshot from a blurry video Brian sent me):

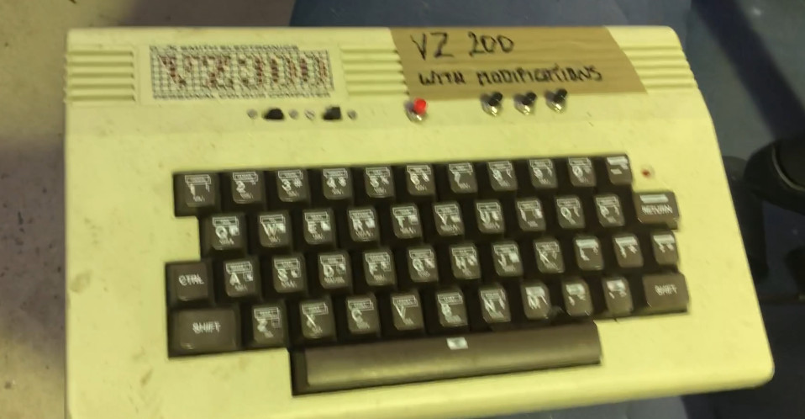
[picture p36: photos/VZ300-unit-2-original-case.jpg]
VZ300 Unit 2 Original Case


I connected power and composite video to unit 2 and got a BASIC prompt.
So other than the missing keyboard, it appeared to be working fine.

## Making a new VZ300!

In summary,

* Unit 1 had a non-working motherboard and a working mechanical keyboard.
* Unit 2 had a working motherboard and a disconnected keyboard.

So I swapped the two motherboards, washed the case, and I now have a
fully working VZ300 in an original case!

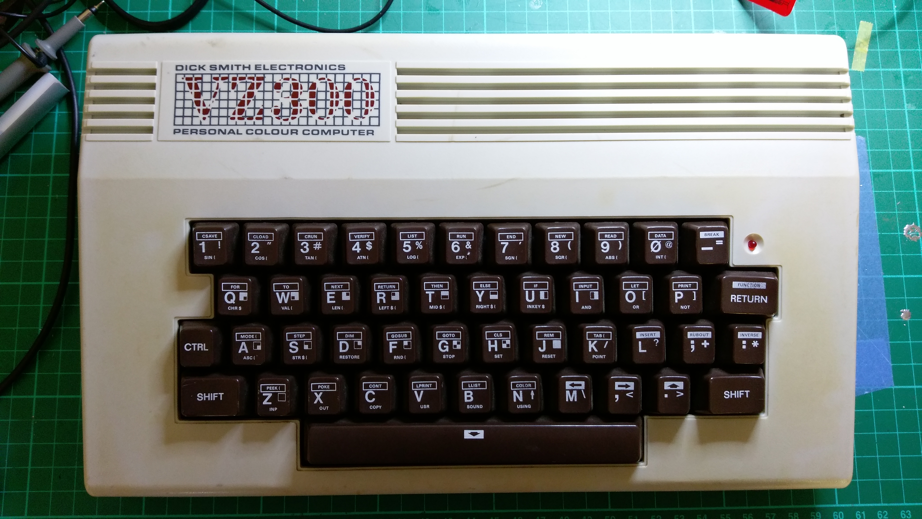
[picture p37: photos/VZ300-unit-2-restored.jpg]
VZ300 Unit 2 Restored


## Back to Unit 1

After some months I got back to the non-working Unit 1 motherboard to
try to figure out what was wrong with it.  The first thing I did was
replace the cut-off keyboard ribbon cable with a pin edge connector,
just as I had done on my other VZ200 and VZ300 boards:

VZ300 Unit 1 With Keyboard Connector

### Screen test

Turning the unit on, garbage is displayed on the screen.  The type of
garbage can vary on each boot-up, but this is typical:

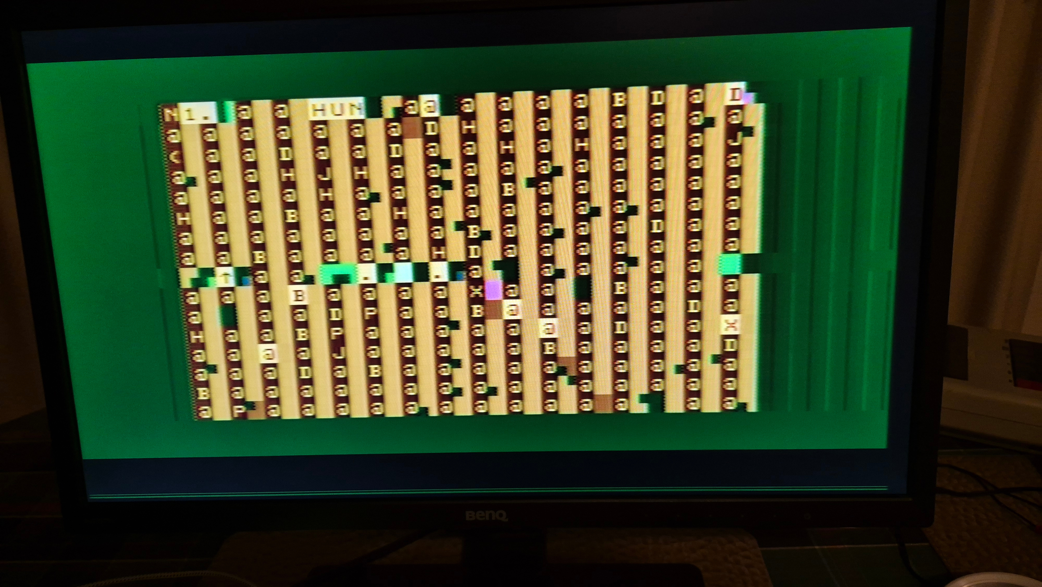
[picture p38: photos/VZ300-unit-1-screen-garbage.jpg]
VZ300 Unit 1 Screen Garbage


The ghosted vertical bars off to the right are "normal" - it also happens
with the other working unit and my RetroTink.  Ignoring that, there are a few
things that we can tell from this screenshot:

* The MC6847 Video Display Generator (U15) is working and displaying
characters from its internal character ROM.
* The 6116 video RAM chip (U16) is also working and retaining the
initial random startup state.
* The CPU has not properly initialized the screen, so the ROM code is
probably not running.  There is no static that may indicate that the
CPU is trying to write to the video RAM.
* The video clock generated by Gate Array 1 (U13) is fine.
* Gate Array 2 (U14) is not interfering with the MC6847's access to
video RAM.
* The CPU and PAL clocks generated by Gate Array 3 (U10) are fine.
* The CSS pin on the MC6847 has not been initialized so the text is using
an orange background instead of the more usual green.  On other
boot-ups, the background is sometimes green.

So it isn't all bad.

### Replacing the ROM

The screenshot is similar-looking to the initial state of my VZ200 before I
restored it:

VZ200 Bad Screen

In the case of the VZ200, the mask ROM's were bad.  Replacing them made the
VZ200 come good.  So the first order of business was to replace the
16K ROM chip (U12) on the VZ300 with a modern 32K AT28C256 EEPROM that
I had lying around.  I duplicated the 16K image into both halves of the
32K AT28C256.  Except for an extra address line, the pinout of the
AT28C256 is identical to the original ROM.

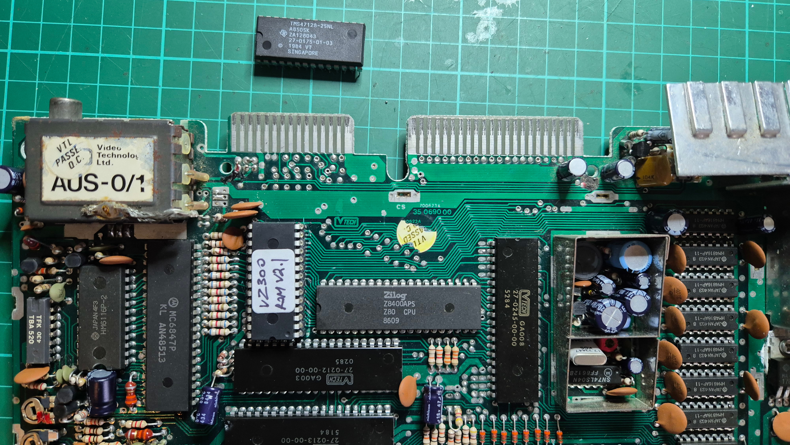
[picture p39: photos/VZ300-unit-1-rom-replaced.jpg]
VZ300 ROM Replaced


This time I used a desoldering pump that I purchased from Amazon.
I didn't tear up any tracks this time, as when I replaced the VZ200's ROM's.

Unfortunately, this didn't make any difference.  The screen was still
corrupted.  The original ROM also tested good in my
<a href="https://store.backbit.io/product/chip-tester/">BackBit Chip Tester Pro</a> and I confirmed that it contained the V2.0 version of the ROM's.
On the plus side, the ROM has now been updated to V2.1!

### ROM Chip Select

I probed around the ROM (U12) with an oscilloscope.  The chip select line
(pin 20) looked a little weird:

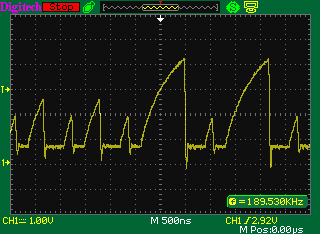
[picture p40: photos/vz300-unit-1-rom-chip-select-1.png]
VZ300 ROM Chip Select 1


The baseline was shifted up by about 0.6V and the shape was definietly
not square.  It looked some kind of RC response.  Looking at the schematic,
there is a diode-AND arrangement that connects pin 20 to the R0 and R1
lines on Gate Array 1 (U13):

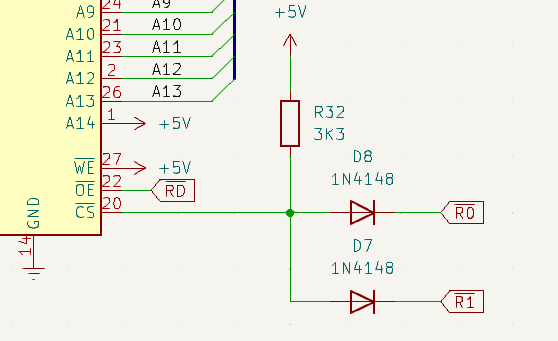
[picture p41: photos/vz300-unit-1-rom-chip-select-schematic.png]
VZ300 ROM Chip Select Schematic


R0 is pulled low for addresses $0000 to $1FFF and R1 is pulled low for
addresses $2000 to $3FFF.  In the original VZ200 design, there were two
8K ROM's in these ranges.  In the VZ300, there is a single 16K ROM.
Hence the diode AND arrangement to combine the two chip selects into one.
The diode voltage drops would account for the 0.6V shift in the baseline.

When I probed the cathode sides of D7 and D8, I got signals that looked
like this:

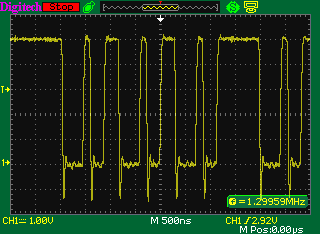
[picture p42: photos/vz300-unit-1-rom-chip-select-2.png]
VZ300 ROM Chip Select 2


That looks almost perfect (the overshoot is probably due to the long ground
lead on my oscilloscope probe).  The widths of the square pulses in this
trace are very similar to the widths of the triangular pulses in the
previous trace.

I replaced R32, D7, and D8, but it didn't make any difference.  I measured
the capacitance on the chip select line at about 2nF.  There was a
capacitor near the ROM, so I temporarily removed it:

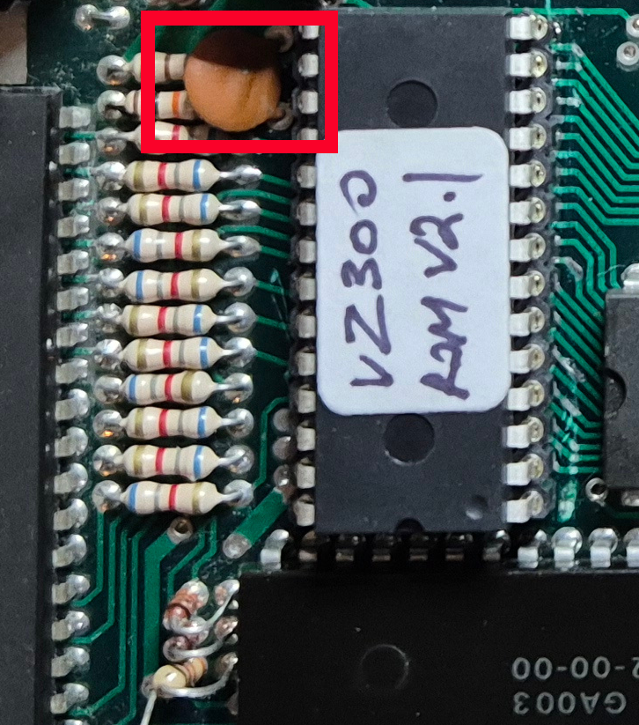
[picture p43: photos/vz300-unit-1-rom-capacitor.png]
VZ300 ROM Capacitor


That did not help - the shape of the chip select waveform was the same.
And now there was video flicker that wasn't there before.  Whatever that
capacitor is used for, it isn't related to the chip select.

I then disassembled Unit 2, which was working, and checked the chip
select line on that.  It had the same weird triangular shape as Unit 1.
So maybe the chip select was a red herring after all ...

### Checking the CPU pins

I probed all of the address, data, and control lines on the Z80 CPU and
they all looked reasonable.

### Checking the dynamic RAM

I probed the eight 4816AP-11 DRAM chips.  The CAS line was stuck high and all
address lines were stuck low.  This was suggesting that Gate Array 3 (U10)
was not decoding the dynamic RAM addresses correctly.  Without working
DRAM, the system would definitely have trouble starting.

As a check, I pulled one of the HM4816AP-11 DRAM chips and tested it.
It was fine.

### Dead Test ROM

Pulling and replacing chips wasn't getting me anywhere.  So I tried a
different approach.  I wrote a small assembly program to initialise video
text mode and fill the screen with a blue checkboard.  I replaced the
BASIC ROM with the program in EEPROM.

I already knew that video RAM and the MC6847 Video Display Generator (VDG)
were working.  If a blue checkboard appeared, then the ROM was working too.
This is what I got:

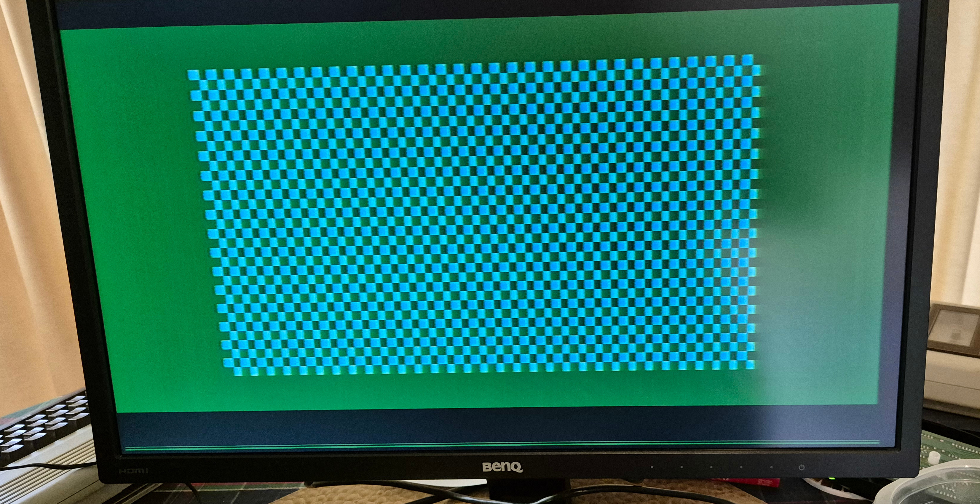
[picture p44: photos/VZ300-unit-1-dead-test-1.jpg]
VZ300 Dead Test 1


Yay!  Now we are getting somewhere.  The system is alive enough to
run code from ROM and display video.  The weird looking chip select is fine.

So I wrote a comprehensive [VZ200/VZ300 Dead Test ROM](src/deadtest/README.md)
to test video, I/O, RAM, VSYNC timing, everything.  On my VZ200, the result
looks like this (all good):

VZ200 Dead Test

On the VZ300, the result was this:

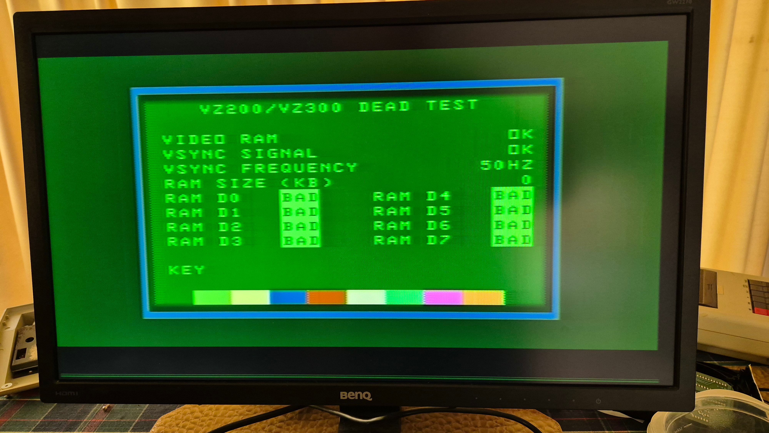
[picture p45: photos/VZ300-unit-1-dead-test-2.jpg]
VZ300 Dead Test 2


Everything is fine except the DRAM.  But I know that the DRAM chip that I
pulled (D6) was working fine.  So it looks like Gate Array 3 (U10) is dead.
That's annoying.

### What is working so far?

So now we know that the CPU, MC6847, ROM, Video RAM, Gate Array 1, and
Gate Array 2 are all working.  The DRAM chips are probably good, but
Gate Array 3 is definitely not.

Gate Array 3 is partially working.  It is responsible for dividing the
17.734MHz clock crystal down to 4.434MHz for the PAL encoder (divide by 4),
and 3.547MHz for the CPU (divide by 5).  These clocks are working fine.
It is just the DRAM interface inside Gate Array 3 that is not working.

### Replacing Gate Array 3

TBD

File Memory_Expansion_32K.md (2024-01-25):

VZ200 32K Memory Expansion Module
=================================

This page describes the 32K Memory Expansion Module that was donated to me.

The case is obviously from a standard 16K Memory Expansion module,
[schematic here](schematics/VZ200_16K_RAM_Expansion/PDF/VZ200_16K_RAM_Expansion.pdf).
However, it is not standard!  The case clearly says "32K" and there is an
inscription in marker pen: "This Unit manufactured by D.Newcombe" and a
phone number.  I have blurred out the phone number:

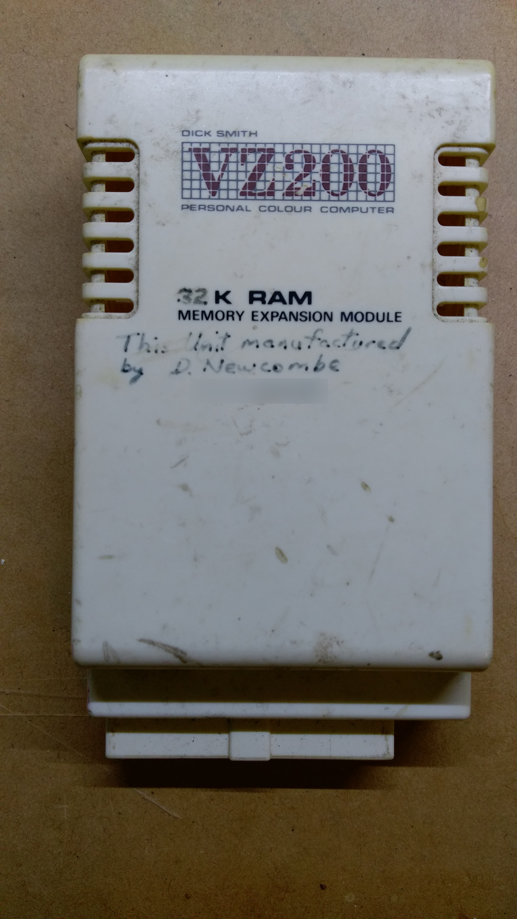
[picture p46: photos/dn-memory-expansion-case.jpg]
Memory Expansion Case


Upon opening the case, I expected to see a normal 16K Memory Expansion
board with the 4116 DRAM's replaced with 4132 or 4164 DRAM's instead,
plus some bodge wires for the extra address lines.  Nope!  It was a
completely different design using four HM6264 8K x 8-bit static RAM
chips and a 74LS138 for address decoding:

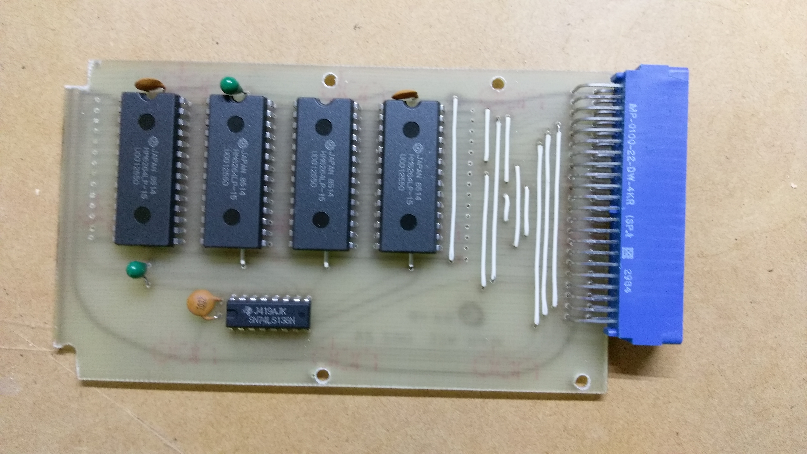
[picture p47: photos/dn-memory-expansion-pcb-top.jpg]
Memory Expansion PCB Top


The copper side of the board has "dn 86" written on it.  I guess that
means "D.Newcombe 1986".  I think the symbol to the right of "dn 86"
is supposed to be a hand-drawn &copy; symbol, but it doesn't look like it
in this picture:

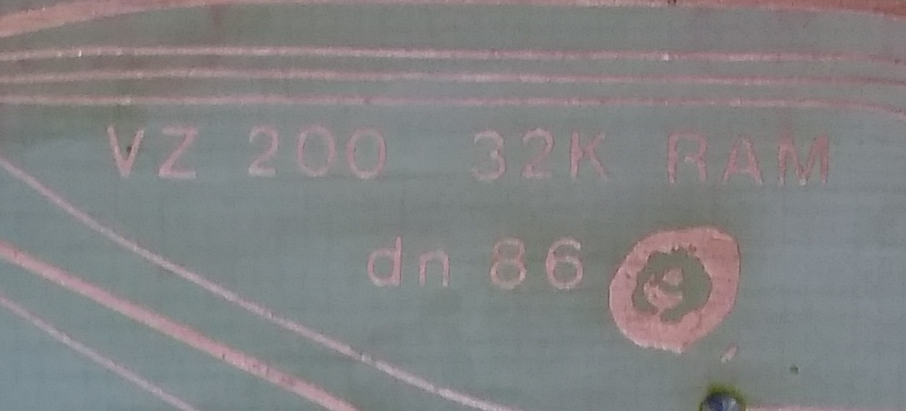
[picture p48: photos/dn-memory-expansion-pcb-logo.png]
Memory Expansion PCB Logo


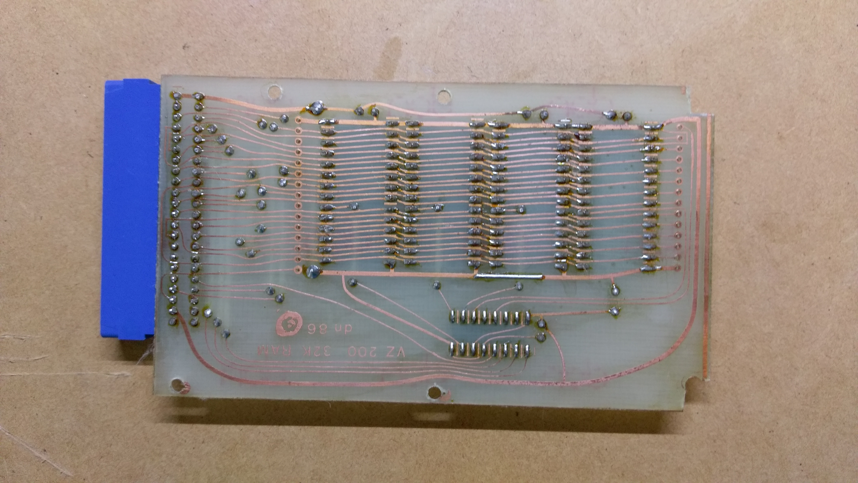
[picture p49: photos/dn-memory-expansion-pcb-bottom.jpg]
Memory Expansion PCB Bottom


I have traced the schematic and redrawn it in KiCad, which you can find
[here](schematics/D_Newcombe_32K_RAM_Expansion/PDF/D_Newcombe_32K_RAM_Expansion.pdf).

I cleaned up the case with Windex and water, and gave the PCB a clean
with isopropyl alcohol.  Works perfectly!

The standard 6K of program RAM on the VZ200 motherboard occupies addresses
$7800 to $8FFF.  The 32K expansion module occupies addresses $8000 to $FFFF.
There is some overlap in the address ranges.

However, this doesn't seem to affect the operation.  When the CPU writes to
addresses between $8000 and $8FFF, it writes to both the internal
program RAM and the expansion RAM.  As long as you don't try to read a
memory location before writing it, there should be no bus conflicts.
Both RAM chips should be driving the bus with the same data values when read.

This expansion RAM design should also work just fine with the Laser 200.
There won't be any address conflicts because the Laser 200 motherboard only
has 2K of program RAM and does not use addresses in the range $8000 to $8FFF.

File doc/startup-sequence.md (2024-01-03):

VZ200 Startup Sequence
======================

This file describes the startup sequence of the VZ200 ROM's, based on a
disassembly of v2.0 of the ROM's.

When the CPU resets, it starts running code at address `$0000` and
proceeds to do the following:

* Disable interrupts with a `DI` instruction.
* Write `$00` to I/O address `$6800` which sets all output pins on U1 to zero.
  * Turns off the speaker and casette outputs.
  * Selects alphanumeric mode in the MC6847 Video Display Generator (VDG).
  * Selects the green background color in the VDG.
* Copies the `$0036` bytes at `$06D2` in ROM to `$7800` in RAM.
  This initialises the system vectors and other variables in RAM.
* The copy is repeated 128 times, which has the effect of producing a
  delay at startup to allow the voltage rails to settle.
* Initialize global variables for the BASIC interpreter.
* Clear the screen.
* Determine the amount of available RAM and populate the top of memory
  pointer in `$78B1` and `$78B2`.
* Print the startup banner message `VIDEO TECHNOLOGY BASIC V2.0`.
* Check the four bytes at `$4000`, `$6000`, and `$8000` looking for the
  pattern `$AA`, `$55`, `$E7`, `$18`.  If that pattern is found, then there
  is a ROM cartridge at that address.  Re-enable interrupts and jump to the
  code that starts at `$4004`, `$6004`, or `$8004` depending upon which
  ROM cartridge was detected.
* Otherwise re-enable interrupts and jump into the BASIC interpreter.

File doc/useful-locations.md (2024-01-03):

VZ200 Useful Locations
======================

This file lists useful memory locations and subroutines on the VZ200.
It is a summary of the data from the manuals, combined with other
information I gleaned along the way.

## 64K Memory Map

* `$0000 - $1FFF` - ROM 0, U9, 8K
* `$2000 - $3FFF` - ROM 1, U10, 8K
* `$4000 - $67FF` - Cartridge ROM, 10K
* `$6800 - $6FFF` - I/O space, U1 and U2, 2K
* `$7000 - $77FF` - Video RAM, U7, 2K
* `$7800 - $8FFF` - User Program RAM, 6K
* `$9000 - $FFFF` - Unused in the base model VZ200, used by the 16K
  memory expansion module.

## I/O Space

Due to how address decoding works, writing to any address in the range
`$6800 - $6FFF` will write the same I/O location.  The bits are
arranged as follows:

* Bit 0 - Speaker A
* Bit 1 - Cassette out A.
* Bit 2 - Cassette out B.
* Bit 3 - VDG display mode; 0 = text mode, 1 = graphics mode.
* Bit 4 - VDG background colour.  In text mode, 0 = green, 1 = orange.
  In graphics mode, 0 = green, 1 = buff.
* Bit 5 - Speaker B.  Setting Speaker A and B to opposite bits, and
  then swapping the two bits, will cause the speaker to emit a single click.
  Rapidly swapping back and forth will play a tone.

Any value that is written to `$6800` should also be written to `$783B` in
RAM to let the BASIC interpreter know the most recent modes that were set.

When reading from addresses in the range `$6800 - $6FFF`, the keyboard
matrix is accessible on bits 0 to 5.  The address selects the specific
row of the keyboard matrix to read:

* `$68FE` - Row 0
* `$68FD` - Row 1
* `$68FB` - Row 2
* `$68F7` - Row 3
* `$68EF` - Row 4
* `$68DF` - Row 5
* `$68BF` - Row 6
* `$687F` - Row 7

A bit that reads as 0 corresponds to a pressed key, and a bit that
reads as 1 corresponds to an unpressed key.  Note that
[key ghosting](https://en.wikipedia.org/wiki/Key_rollover#Key_jamming_and_ghosting)
may occur if 3 or more keys are held down at once.

The following bits have a special meaning when I/O addresses are read:

* Bit 6 - State of the cassette input.
* Bit 7 - State of the frame sync signal from the VDG.

## Peripheral Port

The peripheral port on the back of the device makes the 256-byte I/O
bus of the Z-80 CPU available to peripherals.  The manual reserves the
following regions:

* `$00 - $0F` - Printer, output data on `$0E`, read status on `$00`.
* `$10 - $1F` - Floppy Disk Controller
* `$20 - $2F` - Joystick Interface
* `$30 - $3F` - Communications Modem
* `$70 - $7F` - Memory Bank Switch

The ROM's seem to also make use of I/O ports in the range `$40 - $5F`.
Not sure what they are for.

Usually a peripheral also needs ROM support but the peripheral port does
not make the memory bus accessible.  Only peripherals that have support in
the standard ROM's can be connected to the peripheral port.  If the
peripheral needs custom drivers, then it must be connected to the
memory expansion / cartridge port, with the driver in external ROM.

## System Variables in RAM

* `$7800 - $7802` - Handler for `RST $08`, usually a `JP` or `RET` instruction.
* `$7803 - $7805` - Handler for `RST $10`, usually a `JP` or `RET` instruction.
* `$7806 - $7808` - Handler for `RST $18`, usually a `JP` or `RET` instruction.
* `$7809 - $780B` - Handler for `RST $20`, usually a `JP` or `RET` instruction.
* `$780C - $780E` - Handler for `RST $28`, usually a `JP` or `RET` instruction.
* `$780F - $7811` - Handler for `RST $30`, usually a `JP` or `RET` instruction.
* `$7820 - $7821` - Address of the cursor position between `$7000` and `$71FF`.
* `$783B` - Copy of the output latch; the last value that was written to
  `$6800` in I/O space.
* `$787D - $787F` - Interrupt handler.
* `$788E, $788F` - 16-bit address of the `USR` routine.
* `$789C` - Output device; 0 = screen, 1 = printer, -1 = cassette.
* `$78A0, $78A1` - 16-bit address of the end of BASIC's stack and the
  start of the string variable storage area.
* `$78A4, $78A5` - 16-bit address of the start of the BASIC program.
* `$78B1, $78B2` - 16-bit address of the top of memory.
* `$78F9, $78FA` - 16-bit address of the end of the BASIC program and the
  start of the simple variables table.
* `$78FB, $78FC` - 16-bit address of the start of the dimensioned
  variables table.
* `$7921, $7922` - 16-bit value that was passed to and from the `USR` routine.
* `$79E8` - 8-bit index into the 64-byte BASIC input line buffer.
* `$7AE9` - Default starting location for BASIC programs.

## Useful subroutines in ROM

### 0000 - Reset Vector

Control jumps to here upon CPU reset.

### 0008 - RST $08

Handler for `RST $08`; jumps to the address `$7800`.  By default this
jumps to the "Examine String" routine at `$1C96`.

### 0049 - Keyboard Get

Waits for a character on the keyboard and returns it in A.
Destroys F, BC, DE, and HL.

### 0050 - Screen Get Character

Gets the character under the cursor on the screen into A.  Destroys HL.

### 01C9 - Clear Screen

Clears the screen and moves the cursor to the home position.
Destroys AF, BC, DE, and HL.

### 033A - Character Output

Outputs the character in A to the screen.  All registers are preserved.

### 058D - Print Character

Prints the character in C to the printer.  Returns the printed character
in A and C, and destroys F, B, DE, and HL.

Calling this routine with C = 0 will check the printer status in A only.
Carry will be set if BREAK has been pressed.

### 05C4 - Check Printer Status

Returns the printer status byte in A.  If bit 0 is set, the printer is busy.
If bit 0 is not set, the printer is ready.  BC, DE, and HL are preserved.

### 06A0 - Enable Interrupts and Enter BASIC

Enables interrupts and then jumps to the routine at `$1A19`.

### 1A19 - BASIC Entry Point

Entry point to the BASIC interpreter.  ROM cartridges can jump to this
location to re-enter BASIC when the cartridge program exits.

### 1C90 - Compare HL and DE

Compares HL and DE and sets the C and Z flags appropriately.
HL is destroyed.

Normally this routine is accessed via `RST $18`.

### 1C96 - Examine String

Compares the byte at the address in HL with the value in the calling
function.  If the bytes are the same, HL is incremented and control
returns.  If the bytes differ, then jumps into BASIC with a
"SYNTAX ERROR".

Normally this routine is accessed via `RST $08`.  The following example
checks if the string at HL is "ABC":

    RST $08
    DB  $41
    RST $08
    DB  $42
    RST $08
    DB  $43

### 1D78 - Check Next Character

Fetches the character at HL and clears the carry bit if it is
alphabetic, or sets the carry bit if not.  Whitespace is
skipped automatically.

Normally this routine is accessed via `RST $10`.  However, if DOS
is running then issuing `RST $10` will instead call into DOS.

### 28A7 - String Output

Writes the NUL-terminated string that is pointed to by HL to the screen.
Destroys AF, BC, DE, and HL.

### 2EB8 - Interrupt Handler

Handles interrupts to the CPU on the "INT" line.  Calls the
user-supplied handler at `$787D` and then performs some internal
housekeeping.

Because the "INT" line is hooked up to the frame sync signal of the
MC6847 Video Display Generator (VDG), the interrupt will fire off at
50Hz on PAL systems when interrupts are enabled in the CPU.

### 2EF4 - Keyboard Scan

Scans the keyboard matrix and returns the key that is pressed in A.
Or zero if no key is pressed.  Destroys F, BC, DE, and HL.

### 2EFD - Keyboard Scan Once

Another keyboard scanning routine.  No debouncing?  No echo?  TBD

### 308B - Character Output 2

Outputs the character in A to the screen.  All registers are destroyed.
The routine at `$033A` should be used by user programs instead of this
internal routine.

### 3450 - Beep

Beep the speaker.  Destroys AF, BC, and DE.  HL is preserved.

### 345C - Sound Output

Plays a sound on the speaker.  HL contains the pitch and BC contains the
duration.  Destroys AF, BC, DE, and HL.

### 3AE2 - Print CRLF

Sends a CRLF sequence to the printer.  Destroys AF, BC, DE, and HL.
If BREAK was pressed, then the carry flag will be set.

## Memory Bank Switching

[Andrew Laird's 256K RAM Expansion](http://wiki.vz200.org/index.php?title=Andrew_Laird%27s_256K_RAM_Expansion)
writes the bank number 0..15 to output port `$70` to select which 16K
memory bank to make active.

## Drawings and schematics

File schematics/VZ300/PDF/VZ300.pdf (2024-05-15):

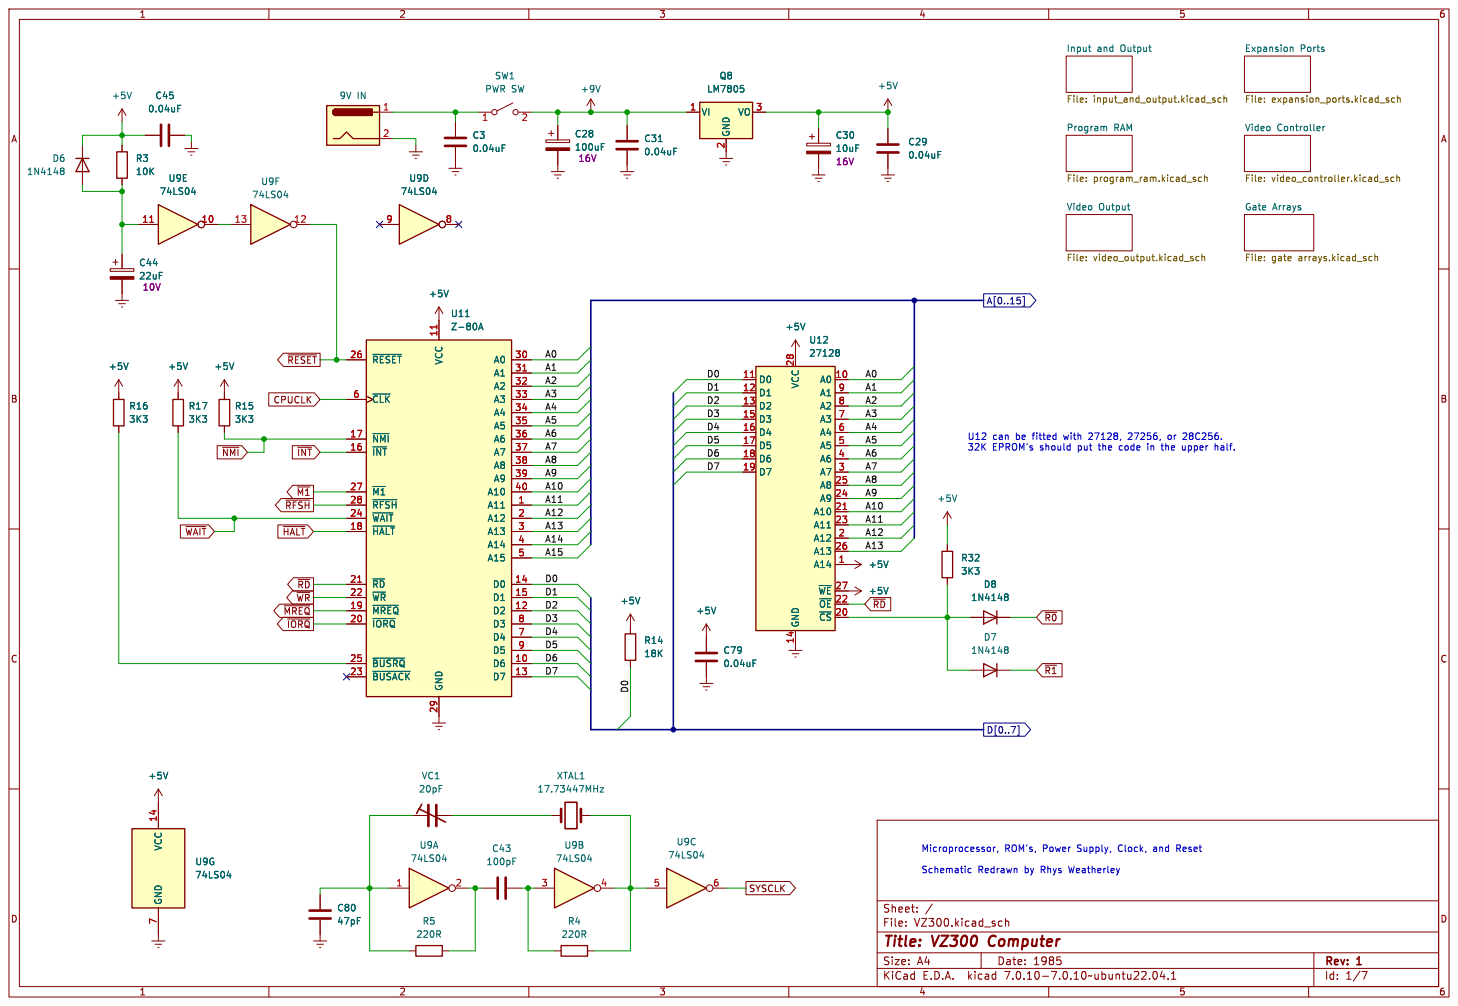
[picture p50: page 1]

Id: 1/7 Title: VZ300 Computer File: VZ300.kicad_sch Sheet: /

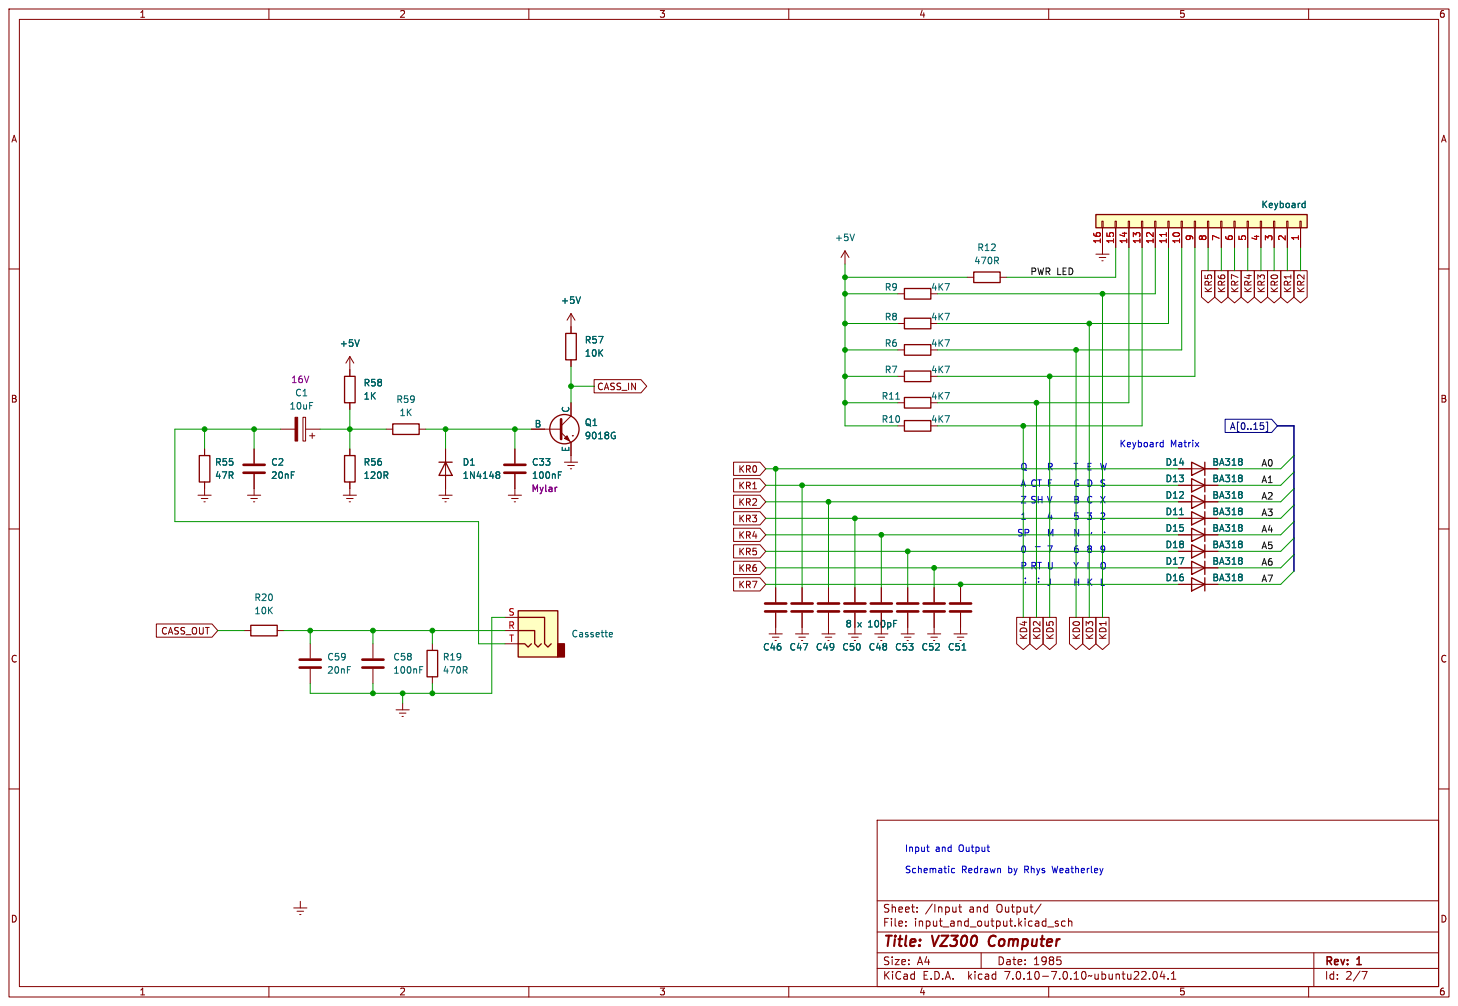
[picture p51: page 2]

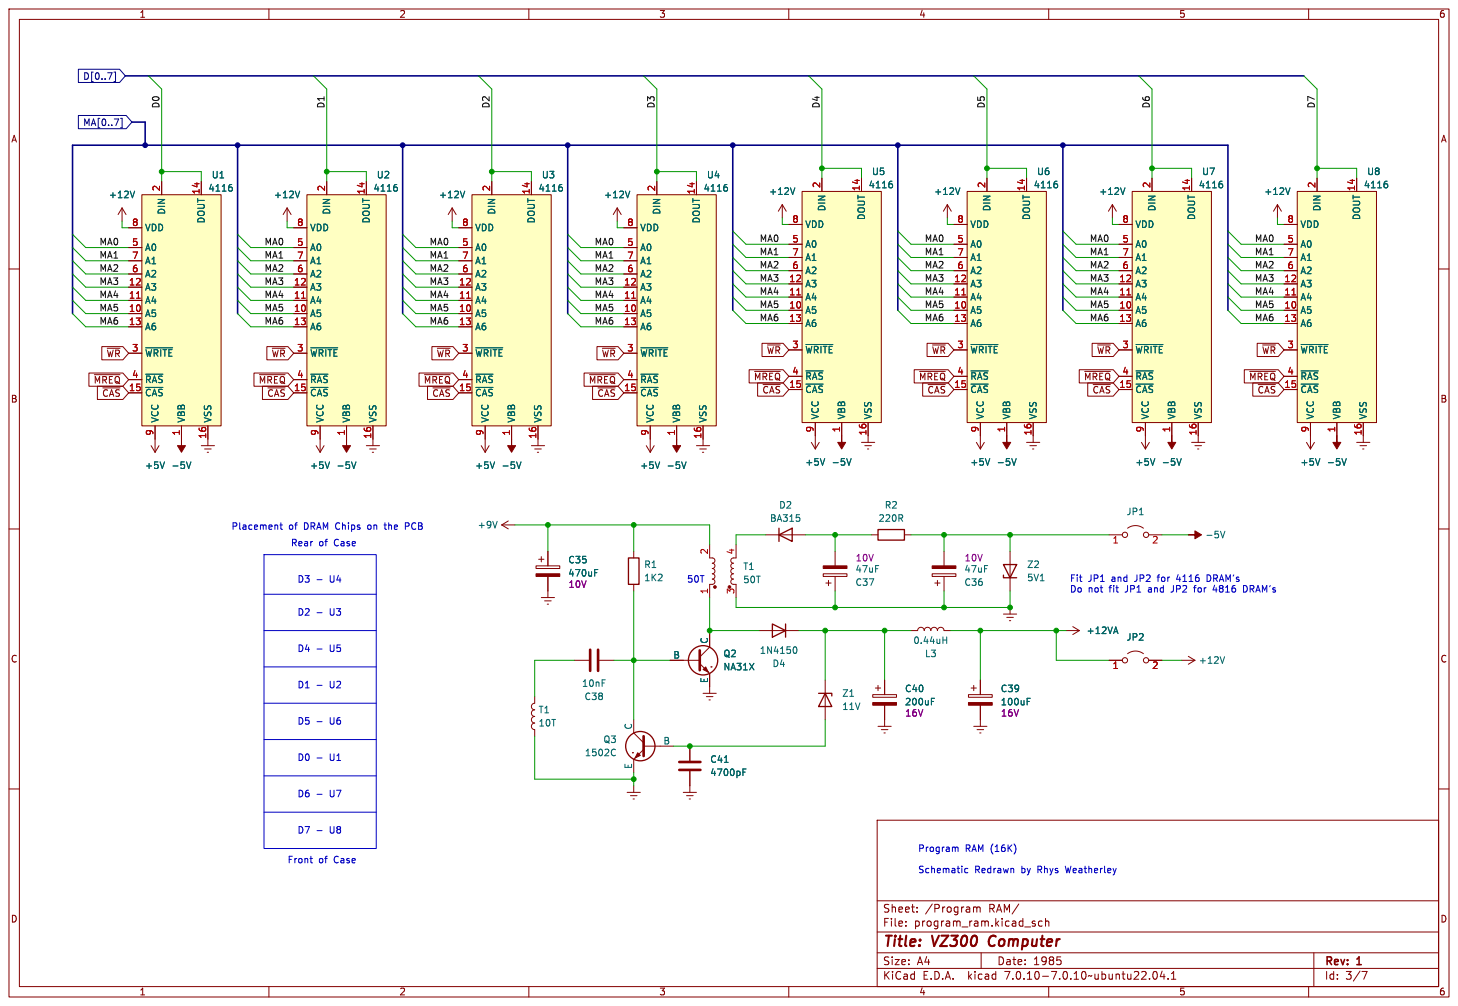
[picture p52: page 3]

2 ~{WRITE} 3 ~{RAS} 4 A0 5 A2 6 A1 7 VDD 8 VCC

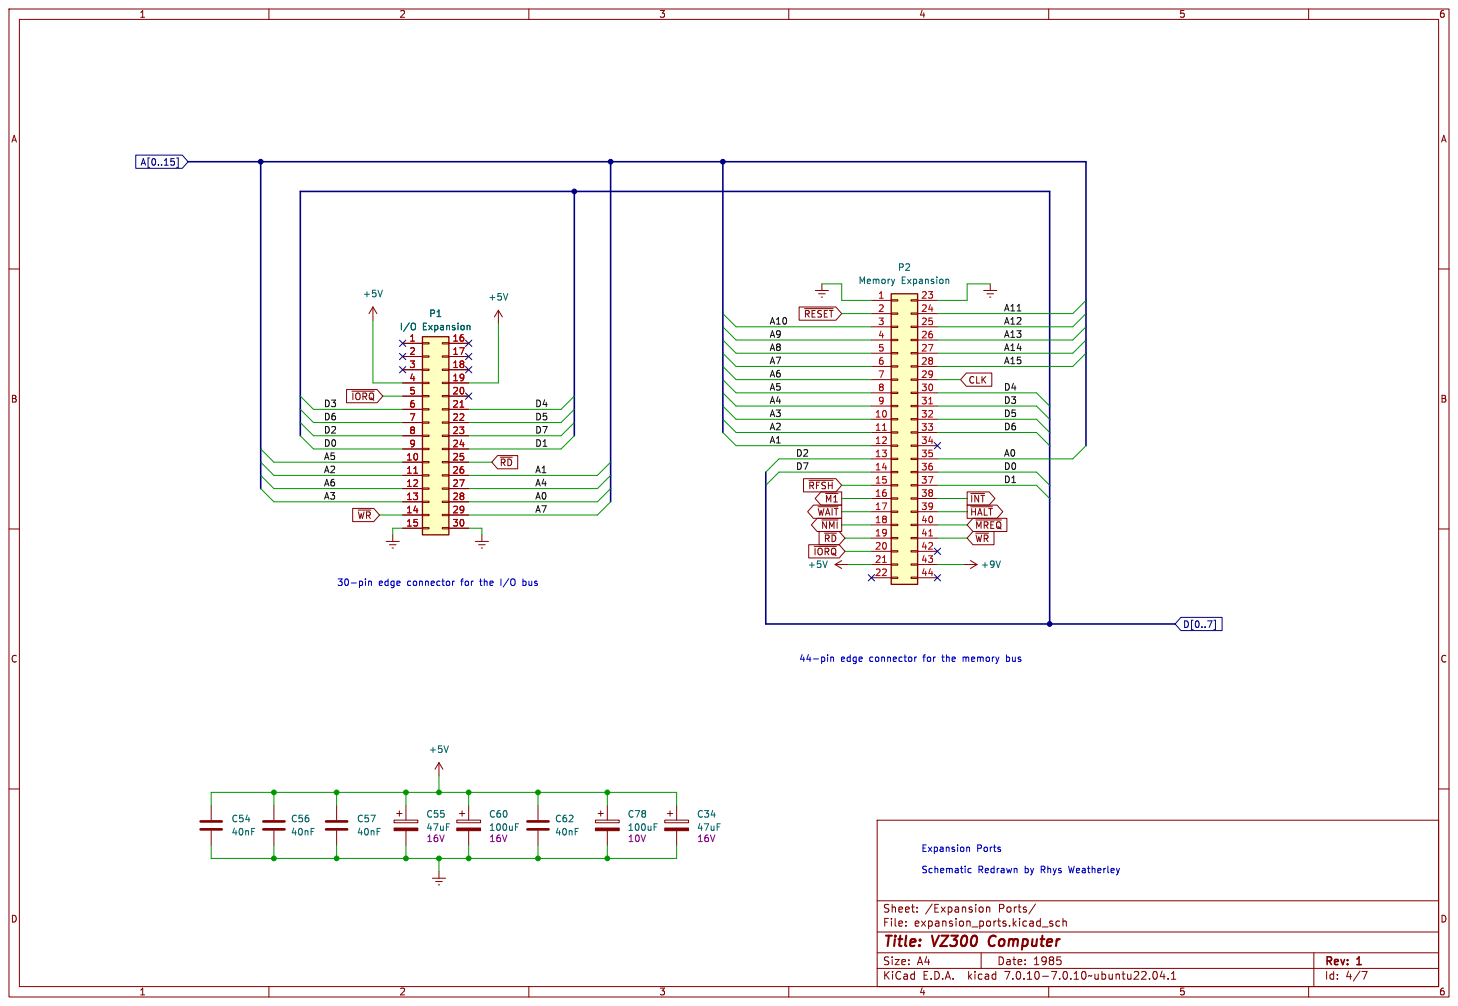
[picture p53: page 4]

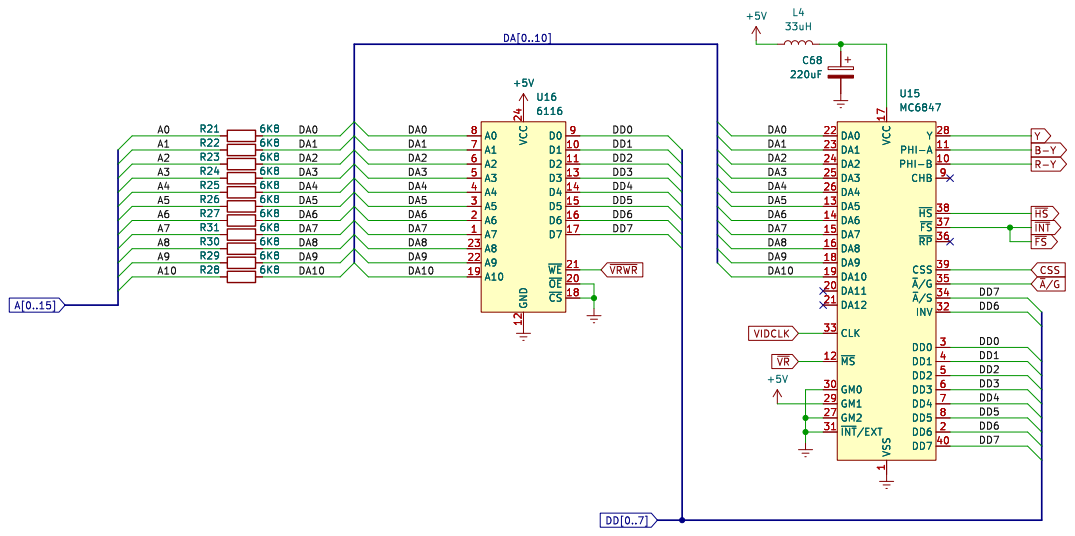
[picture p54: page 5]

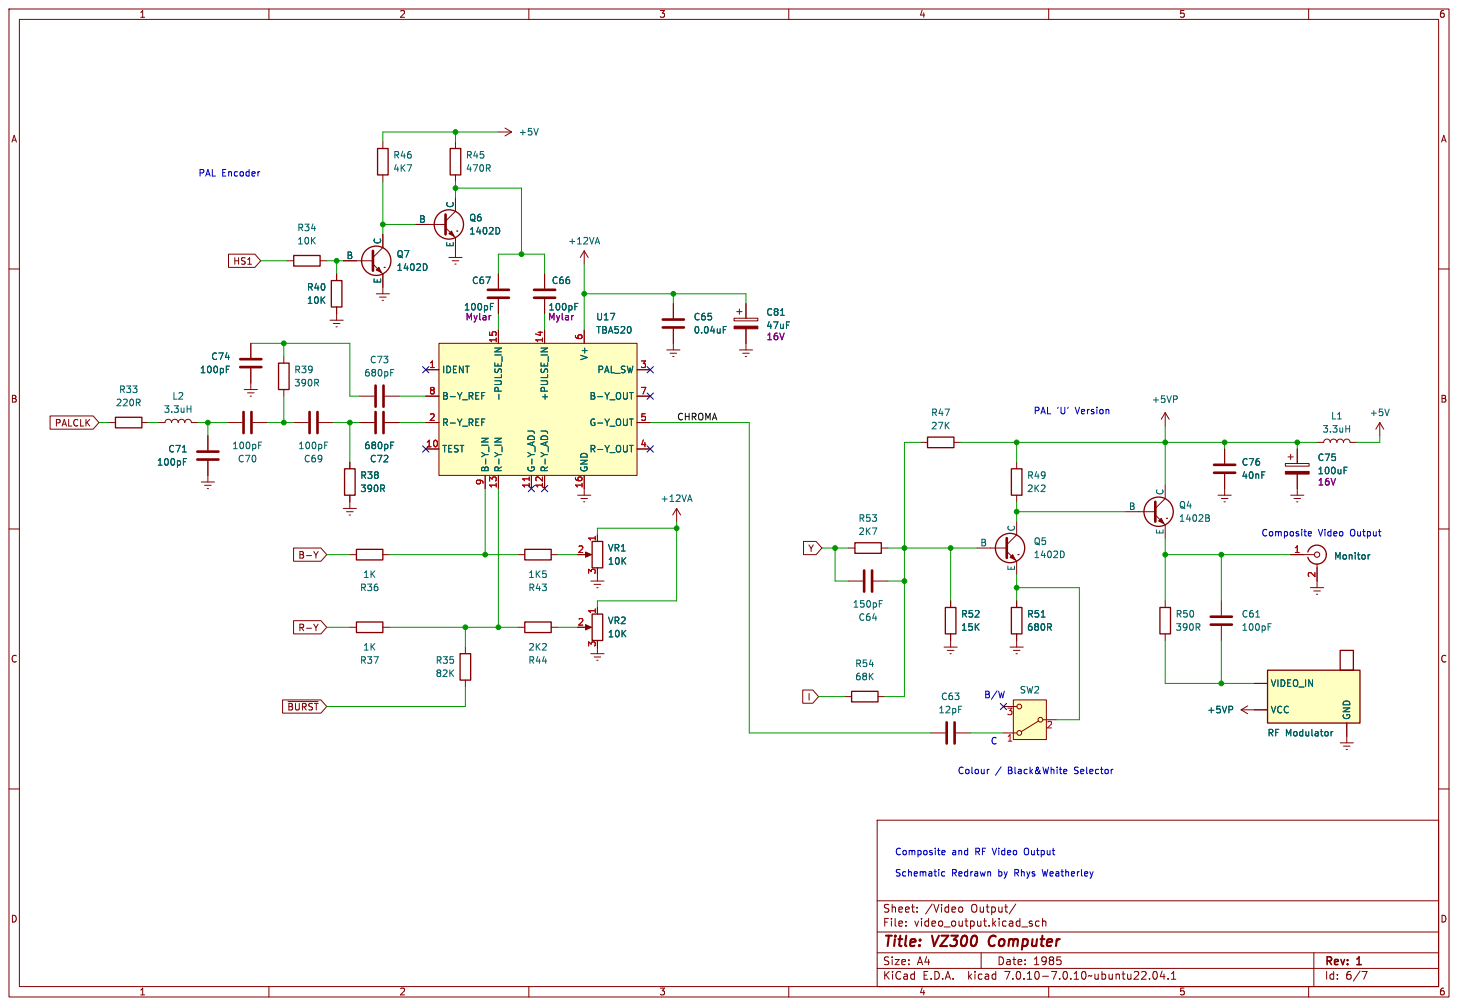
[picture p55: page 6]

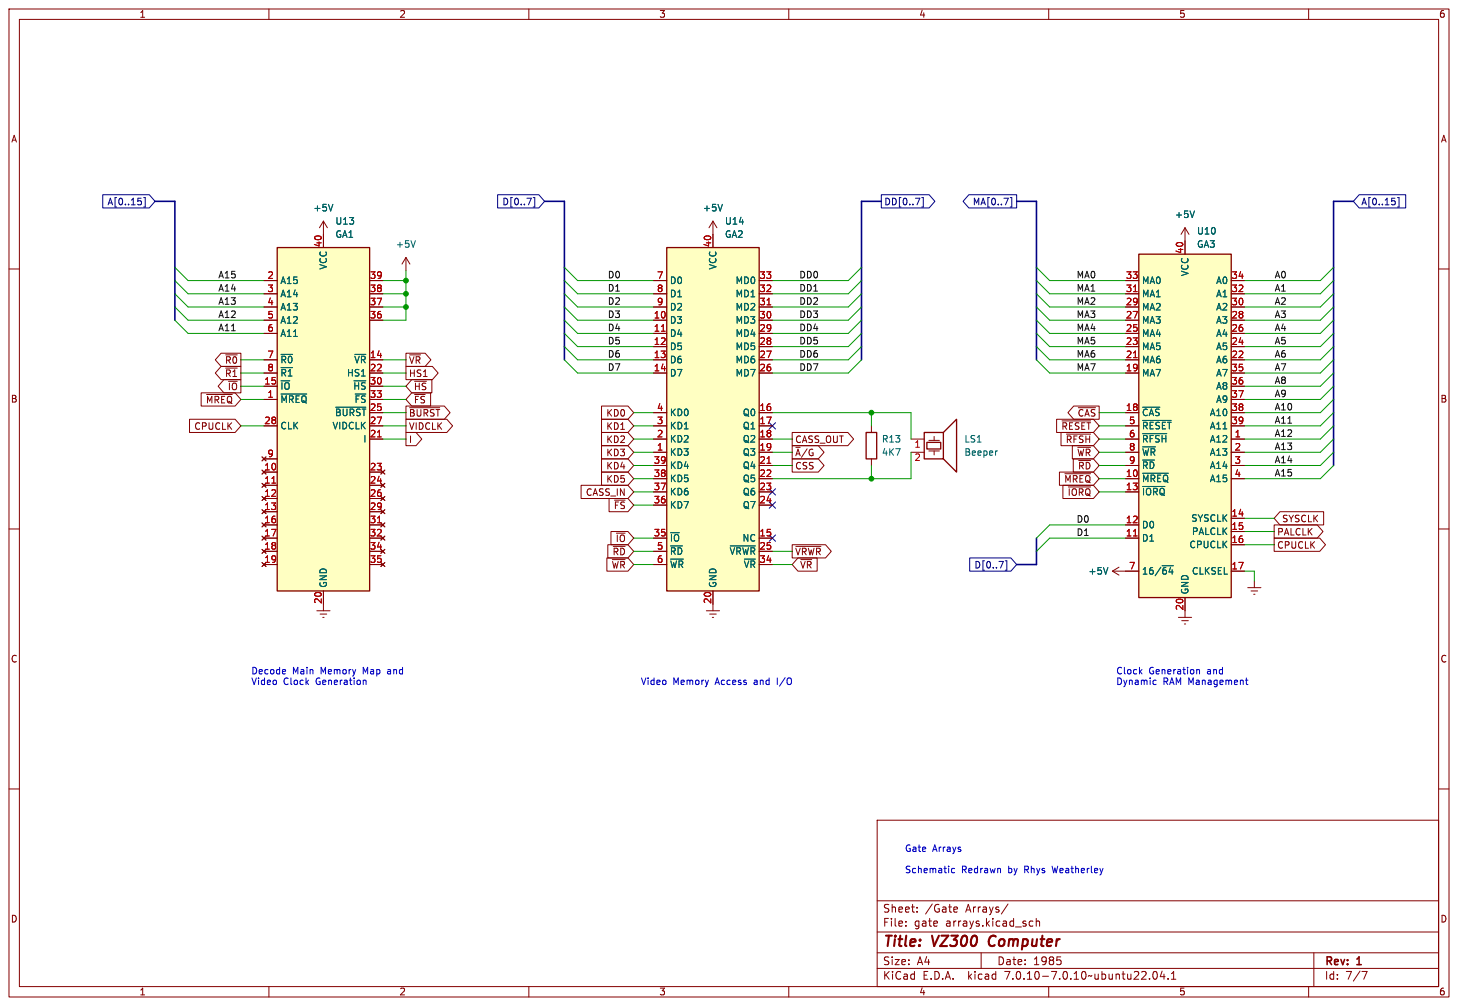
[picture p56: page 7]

Id: 7/7 Title: VZ300 Computer File: gate arrays.kicad_sch Sheet: /Gate Arrays/

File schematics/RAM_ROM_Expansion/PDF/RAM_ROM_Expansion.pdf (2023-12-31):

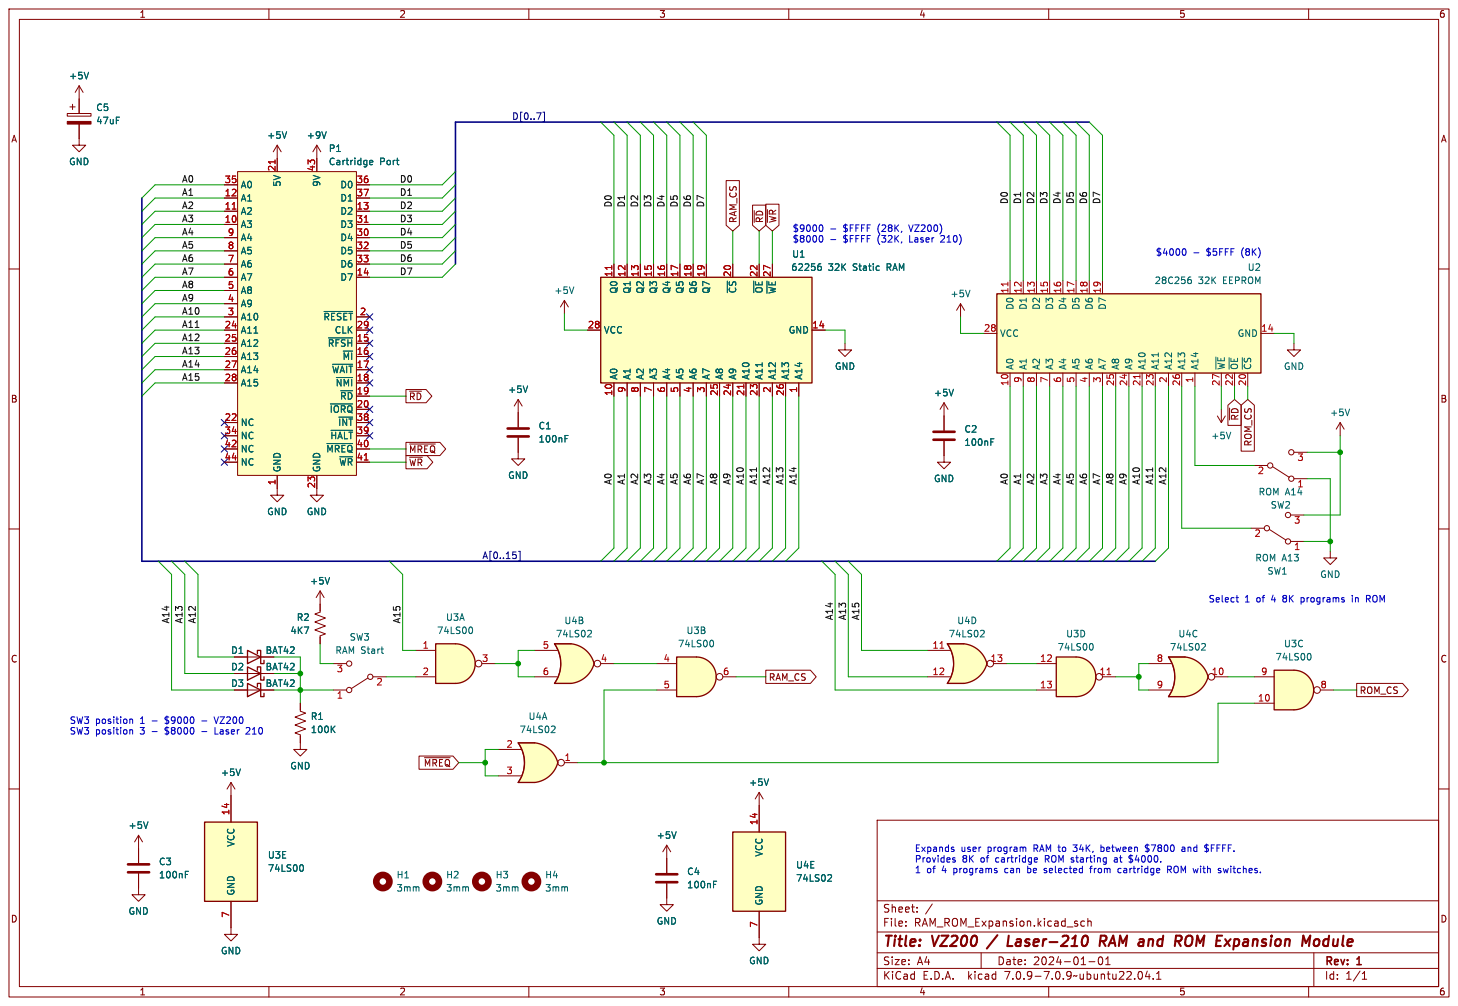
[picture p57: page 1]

1 A3 10 A2 11 A1 12 D2 13 D7 14 ~{RFSH} 15 ~{MI} 16 ~{WAIT} 17 ~{NMI}18 ~{RD} 19 ~{RESET}2 ~{IORQ} 20 5V 21 NC 22 GND 23 A11 24 A12 25 A13 26 A14 27 A15 28 CLK 29 A10 3 D4 30 D3 31 D5 32 D6 33 NC 34 A0 35 D0 36 D1 37 ~{INT} 38 ~{HALT} 39 A9 4 ~{MREQ} 40 ~{WR} 41 NC 42 9V 43 NC 44 A8 5 A7 6 A6 7 A5 8 A4 9 P1Cartridge Port

1 A3 10 A2 11 A1 12 D2 13 D7 14 ~{RFSH} 15 ~{MI} 16 ~{WAIT} 17 ~{NMI}18 ~{RD} 19 ~{RESET}2 ~{IORQ} 20 5V 21 NC 22 GND 23 A11 24 A12 25 A13 26 A14 27 A15 28 CLK 29 A10 3 D4 30 D3 31 D5 32 D6 33 NC 34 A0 35 D0 36 D1 37 ~{INT} 38 ~{HALT} 39 A9 4 ~{MREQ} 40 ~{WR} 41 NC 42 9V 43 NC 44 A8 5 A7 6 A6 7 A5 8 A4 9 R1

2 ~{CS} 20 A10 21 ~{OE} 22 A11 23 A9 24 A8 25 A13 26 ~{WE} 27 VCC 28 A7

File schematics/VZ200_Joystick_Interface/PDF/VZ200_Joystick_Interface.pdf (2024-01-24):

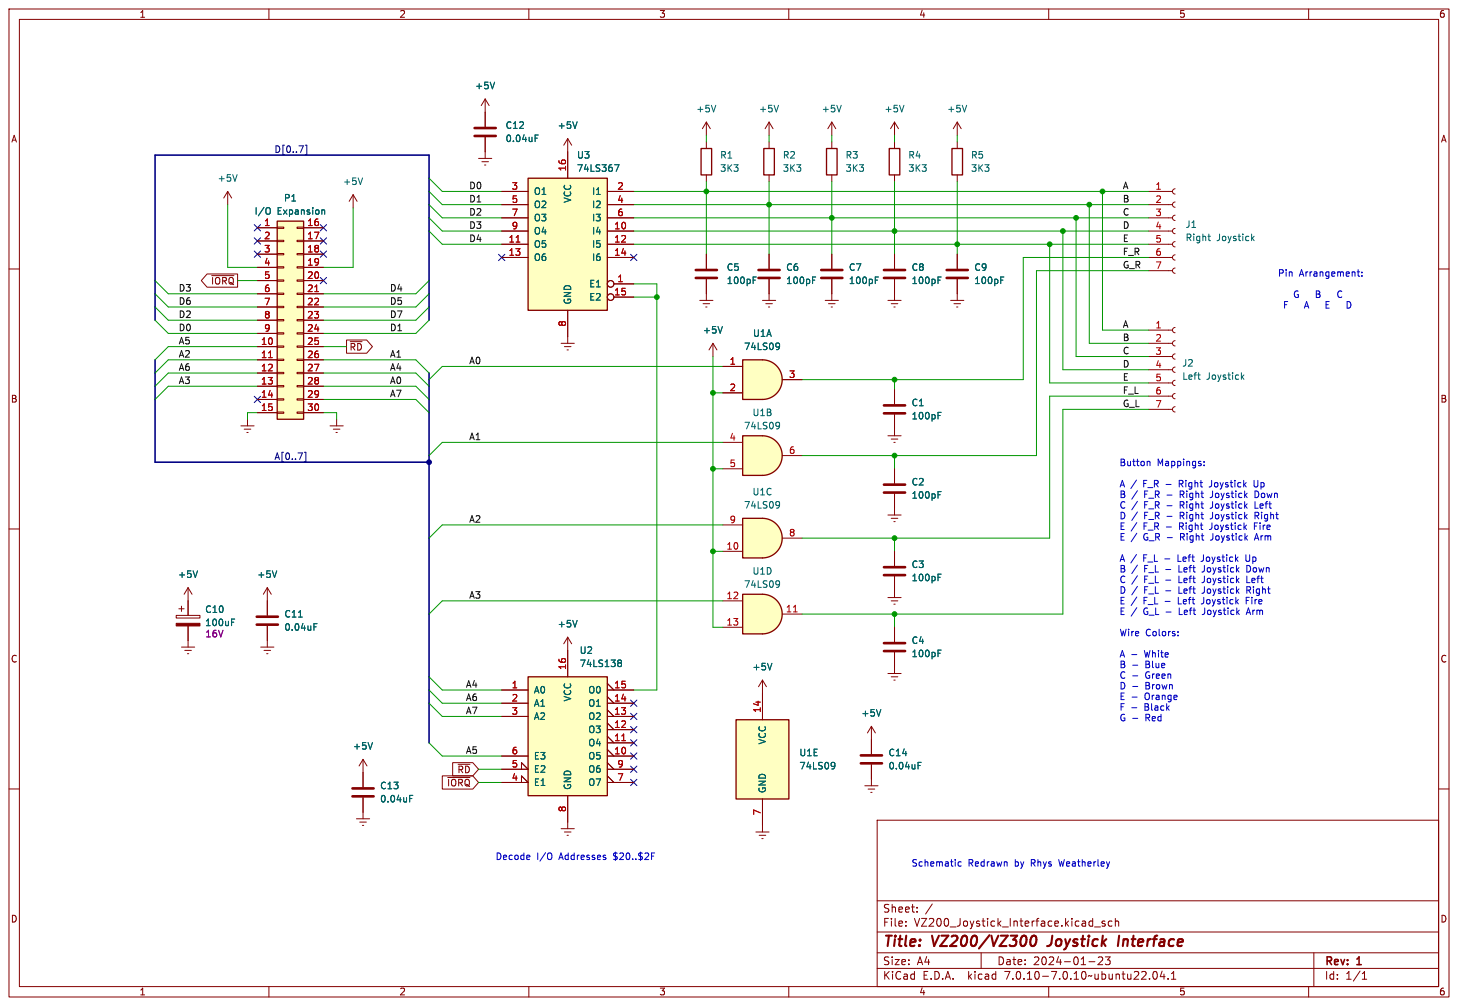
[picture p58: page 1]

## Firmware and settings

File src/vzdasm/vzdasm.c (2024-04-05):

/*
 * Copyright (C) 2024 Rhys Weatherley
 *
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
 * THE SOFTWARE IS PROVIDED "AS IS", WITHOUT WARRANTY OF ANY KIND, EXPRESS
 * OR IMPLIED, INCLUDING BUT NOT LIMITED TO THE WARRANTIES OF MERCHANTABILITY,
 * FITNESS FOR A PARTICULAR PURPOSE AND NONINFRINGEMENT. IN NO EVENT SHALL THE
 * AUTHORS OR COPYRIGHT HOLDERS BE LIABLE FOR ANY CLAIM, DAMAGES OR OTHER
 * LIABILITY, WHETHER IN AN ACTION OF CONTRACT, TORT OR OTHERWISE, ARISING
 * FROM, OUT OF OR IN CONNECTION WITH THE SOFTWARE OR THE USE OR OTHER
 * DEALINGS IN THE SOFTWARE.
 */

#include <stdio.h>
#include <string.h>

/* Opcode list from https://clrhome.org/table/ */
/*
 * N  - Single-byte operand.
 * NN - Two-byte operand.
 * R  - Single-byte relative operand.
 * D  - Single-byte displacement operand.
 */
static const char * const opcodes_main[256] = {
/*          0               1               2               3               4               5               6               7 */
/* 0x00 */  "nop",          "ld bc,NN",     "ld (bc),a",    "inc bc",       "inc b",        "dec b",        "ld b,N",       "rlca",
/* 0x08 */  "ex af,af'",    "add hl,bc",    "ld a,(bc)",    "dec bc",       "inc c",        "dec c",        "ld c,N",       "rrca",
/* 0x10 */  "djnz R",       "ld de,NN",     "ld (de),a",    "inc de",       "inc d",        "dec d",        "ld d,N",       "rla",
/* 0x18 */  "jr R",         "add hl,de",    "ld a,(de)",    "dec de",       "inc e",        "dec e",        "ld e,N",       "rra",
/* 0x20 */  "jr nz,R",      "ld hl,NN",     "ld (NN),hl",   "inc hl",       "inc h",        "dec h",        "ld h,N",       "daa",
/* 0x28 */  "jr z,R",       "add hl,hl",    "ld hl,(NN)",   "dec hl",       "inc l",        "dec l",        "ld l,N",       "cpl",
/* 0x30 */  "jr nc,R",      "ld sp,NN",     "ld (NN),a",    "inc sp",       "inc (hl)",     "dec (hl)",     "ld (hl),N",    "scf",
/* 0x38 */  "jr c,R",       "add hl,sp",    "ld a,(NN)",    "dec sp",       "inc a",        "dec a",        "ld a,N",       "ccf",
/* 0x40 */  "ld b,b",       "ld b,c",       "ld b,d",       "ld b,e",       "ld b,h",       "ld b,l",       "ld b,(hl)",    "ld b,a",
/* 0x48 */  "ld c,b",       "ld c,c",       "ld c,d",       "ld c,e",       "ld c,h",       "ld c,l",       "ld c,(hl)",    "ld c,a",
/* 0x50 */  "ld d,b",       "ld d,c",       "ld d,d",       "ld d,e",       "ld d,h",       "ld d,l",       "ld d,(hl)",    "ld d,a",
/* 0x58 */  "ld e,b",       "ld e,c",       "ld e,d",       "ld e,e",       "ld e,h",       "ld e,l",       "ld e,(hl)",    "ld e,a",
/* 0x60 */  "ld h,b",       "ld h,c",       "ld h,d",       "ld h,e",       "ld h,h",       "ld h,l",       "ld h,(hl)",    "ld h,a",
/* 0x68 */  "ld l,b",       "ld l,c",       "ld l,d",       "ld l,e",       "ld l,h",       "ld l,l",       "ld l,(hl)",    "ld l,a",
/* 0x70 */  "ld (hl),b",    "ld (hl),c",    "ld (hl),d",    "ld (hl),e",    "ld (hl),h",    "ld (hl),l",    "halt",         "ld (hl),a",
/* 0x78 */  "ld a,b",       "ld a,c",       "ld a,d",       "ld a,e",       "ld a,h",       "ld a,l",       "ld a,(hl)",    "ld a,a",
/* 0x80 */  "add a,b",      "add a,c",      "add a,d",      "add a,e",      "add a,h",      "add a,l",      "add a,(hl)",   "add a,a",
/* 0x88 */  "adc a,b",      "adc a,c",      "adc a,d",      "adc a,e",      "adc a,h",      "adc a,l",      "adc a,(hl)",   "adc a,a",
/* 0x90 */  "sub b",        "sub c",        "sub d",        "sub e",        "sub h",        "sub l",        "sub (hl)",     "sub a",
/* 0x98 */  "sbc a,b",      "sbc a,c",      "sbc a,d",      "sbc a,e",      "sbc a,h",      "sbc a,l",      "sbc a,(hl)",   "sbc a,a",
/* 0xA0 */  "and b",        "and c",        "and d",        "and e",        "and h",        "and l",        "and (hl)",     "and a",
/* 0xA8 */  "xor b",        "xor c",        "xor d",        "xor e",        "xor h",        "xor l",        "xor (hl)",     "xor a",
/* 0xB0 */  "or b",         "or c",         "or d",         "or e",         "or h",         "or l",         "or (hl)",      "or a",
/* 0xB8 */  "cp b",         "cp c",         "cp d",         "cp e",         "cp h",         "cp l",         "cp (hl)",      "cp a",
/* 0xC0 */  "ret nz",       "pop bc",       "jp nz,NN",     "jp NN",        "call nz,NN",   "push bc",      "add a,N",      "rst $00",
/* 0xC8 */  "ret z",        "ret",          "jp z,NN",      NULL,           "call z,NN",    "call NN",      "adc a,N",      "rst $08",
/* 0xD0 */  "ret nc",       "pop de",       "jp nc,NN",     "out (N),a",    "call nc,NN",   "push de",      "sub N",        "rst $10",
/* 0xD8 */  "ret c",        "exx",          "jp c,NN",      "in a,(N)",     "call c,NN",    NULL,           "sbc a,N",      "rst $18",
/* 0xE0 */  "ret po",       "pop hl",       "jp po,NN",     "ex (sp),hl",   "call po,NN",   "push hl",      "and N",        "rst $20",
/* 0xE8 */  "ret pe",       "jp (hl)",      "jp pe,NN",     "ex de,hl",     "call pe,NN",   NULL,           "xor N",        "rst $28",
/* 0xF0 */  "ret p",        "pop af",       "jp p,NN",      "di",           "call p,NN",    "push af",      "or N",         "rst $30",
/* 0xF8 */  "ret m",        "ld sp,hl",     "jp m,NN",      "ei",           "call m,NN",    NULL,           "cp N",         "rst $38",
};

/* Bit instruction opcodes that are prefixed by 0xCB */
static const char * const opcodes_cb[256] = {
/*          0               1               2               3               4               5               6               7 */
/* 0x00 */  "rlc b",        "rlc c",        "rlc d",        "rlc e",        "rlc h",        "rlc l",        "rlc (hl)",     "rlc a",
/* 0x08 */  "rrc b",        "rrc c",        "rrc d",        "rrc e",        "rrc h",        "rrc l",        "rrc (hl)",     "rrc a",
/* 0x10 */  "rl b",         "rl c",         "rl d",         "rl e",         "rl h",         "rl l",         "rl (hl)",      "rl a",
/* 0x18 */  "rr b",         "rr c",         "rr d",         "rr e",         "rr h",         "rr l",         "rr (hl)",      "rr a",
/* 0x20 */  "sla b",        "sla c",        "sla d",        "sla e",        "sla h",        "sla l",        "sla (hl)",     "sla a",
/* 0x28 */  "sra b",        "sra c",        "sra d",        "sra e",        "sra h",        "sra l",        "sra (hl)",     "sra a",
/* 0x30 */  "",             "",             "",             "",             "",             "",             "",             "",
/* 0x38 */  "srl b",        "srl c",        "srl d",        "srl e",        "srl h",        "srl l",        "srl (hl)",     "srl a",
/* 0x40 */  "bit 0,b",      "bit 0,c",      "bit 0,d",      "bit 0,e",      "bit 0,h",      "bit 0,l",      "bit 0,(hl)",   "bit 0,a",
/* 0x48 */  "bit 1,b",      "bit 1,c",      "bit 1,d",      "bit 1,e",      "bit 1,h",      "bit 1,l",      "bit 1,(hl)",   "bit 1,a",
/* 0x50 */  "bit 2,b",      "bit 2,c",      "bit 2,d",      "bit 2,e",      "bit 2,h",      "bit 2,l",      "bit 2,(hl)",   "bit 2,a",
/* 0x58 */  "bit 3,b",      "bit 3,c",      "bit 3,d",      "bit 3,e",      "bit 3,h",      "bit 3,l",      "bit 3,(hl)",   "bit 3,a",
/* 0x60 */  "bit 4,b",      "bit 4,c",      "bit 4,d",      "bit 4,e",      "bit 4,h",      "bit 4,l",      "bit 4,(hl)",   "bit 4,a",
/* 0x68 */  "bit 5,b",      "bit 5,c",      "bit 5,d",      "bit 5,e",      "bit 5,h",      "bit 5,l",      "bit 5,(hl)",   "bit 5,a",
/* 0x70 */  "bit 6,b",      "bit 6,c",      "bit 6,d",      "bit 6,e",      "bit 6,h",      "bit 6,l",      "bit 6,(hl)",   "bit 6,a",
/* 0x78 */  "bit 7,b",      "bit 7,c",      "bit 7,d",      "bit 7,e",      "bit 7,h",      "bit 7,l",      "bit 7,(hl)",   "bit 7,a",
/* 0x80 */  "res 0,b",      "res 0,c",      "res 0,d",      "res 0,e",      "res 0,h",      "res 0,l",      "res 0,(hl)",   "res 0,a",
/* 0x88 */  "res 1,b",      "res 1,c",      "res 1,d",      "res 1,e",      "res 1,h",      "res 1,l",      "res 1,(hl)",   "res 1,a",
/* 0x90 */  "res 2,b",      "res 2,c",      "res 2,d",      "res 2,e",      "res 2,h",      "res 2,l",      "res 2,(hl)",   "res 2,a",
/* 0x98 */  "res 3,b",      "res 3,c",      "res 3,d",      "res 3,e",      "res 3,h",      "res 3,l",      "res 3,(hl)",   "res 3,a",
/* 0xA0 */  "res 4,b",      "res 4,c",      "res 4,d",      "res 4,e",      "res 4,h",      "res 4,l",      "res 4,(hl)",   "res 4,a",
/* 0xA8 */  "res 5,b",      "res 5,c",      "res 5,d",      "res 5,e",      "res 5,h",      "res 5,l",      "res 5,(hl)",   "res 5,a",
/* 0xB0 */  "res 6,b",      "res 6,c",      "res 6,d",      "res 6,e",      "res 6,h",      "res 6,l",      "res 6,(hl)",   "res 6,a",
/* 0xB8 */  "res 7,b",      "res 7,c",      "res 7,d",      "res 7,e",      "res 7,h",      "res 7,l",      "res 7,(hl)",   "res 7,a",
/* 0xC0 */  "set 0,b",      "set 0,c",      "set 0,d",      "set 0,e",      "set 0,h",      "set 0,l",      "set 0,(hl)",   "set 0,a",
/* 0xC8 */  "set 1,b",      "set 1,c",      "set 1,d",      "set 1,e",      "set 1,h",      "set 1,l",      "set 1,(hl)",   "set 1,a",
/* 0xD0 */  "set 2,b",      "set 2,c",      "set 2,d",      "set 2,e",      "set 2,h",      "set 2,l",      "set 2,(hl)",   "set 2,a",
/* 0xD8 */  "set 3,b",      "set 3,c",      "set 3,d",      "set 3,e",      "set 3,h",      "set 3,l",      "set 3,(hl)",   "set 3,a",
/* 0xE0 */  "set 4,b",      "set 4,c",      "set 4,d",      "set 4,e",      "set 4,h",      "set 4,l",      "set 4,(hl)",   "set 4,a",
/* 0xE8 */  "set 5,b",      "set 5,c",      "set 5,d",      "set 5,e",      "set 5,h",      "set 5,l",      "set 5,(hl)",   "set 5,a",
/* 0xF0 */  "set 6,b",      "set 6,c",      "set 6,d",      "set 6,e",      "set 6,h",      "set 6,l",      "set 6,(hl)",   "set 6,a",
/* 0xF8 */  "set 7,b",      "set 7,c",      "set 7,d",      "set 7,e",      "set 7,h",      "set 7,l",      "set 7,(hl)",   "set 7,a",
};
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
int main(int argc, char *argv[])
{
    const char *input;
    unsigned address = 0;
    int unknown = 0;
    FILE *in;

    /* Parse the command-line arguments */
    if (argc < 2) {
        return 1;
    }
    input = argv[1];

    /* Read the input file into memory */
    if ((in = fopen(input, "rb")) == NULL) {
        perror(input);
        return 1;
    }
    data_len = fread(data, 1, sizeof(data), in);
    fclose(in);

    /* Determine what format the file is in from the header */
    if (is_magic(header_cartridge, sizeof(header_cartridge))) {
        /* Looks like a ROM cartridge image */
        address = 0x4000 + sizeof(header_cartridge);
        while (data_len > sizeof(header_cartridge)) {
            /* Strip 0xFF bytes from the end of the ROM image */
            if (data[data_len - 1] != 0xFF)
                break;
            --data_len;
        }
        disassemble(stdout, address, data + sizeof(header_cartridge), data_len - sizeof(header_cartridge));
    } else if (is_magic(header_rom0, sizeof(header_rom0))) {
        /* Looks like the standard VZ U9 ROM at address 0x0000 */
        address = 0x0000;
        load_basic_tokens(data);
        disassemble(stdout, address, data, data_len);
    } else if (is_magic(header_rom1, sizeof(header_rom1))) {
        /* Looks like the standard VZ U10 ROM at address 0x2000 */
        address = 0x2000;
        disassemble(stdout, address, data, data_len);
    } else if ((is_magic(header_vzfile1, sizeof(header_vzfile1)) ||
                is_magic(header_vzfile2, sizeof(header_vzfile2)) ||
                is_magic(header_vzfile3, sizeof(header_vzfile3))) && data_len > 24) {
        /* Looks like a ".VZ" file, which is either a BASIC program
         * or an encapsulated machine code program. */
        address = data[22] + (((unsigned)(data[23])) << 8);
        if (data[21] == 0xF0) {
            /* BASIC program */
            list_basic(stdout, data + 24, data_len - 24);
        } else if (data[21] == 0xF1) {
            /* Machine code program */
            disassemble(stdout, address, data + 24, data_len - 24);
        } else {
            unknown = 1;
        }
    } else {
        unknown = 1;
    }
    if (unknown) {
        fprintf(stderr, "%s: unknown file format\n", input);
        return 1;
    }
    return 0;
}

/* Determine the number of operand bytes on the instruction */
static size_t operand_size(const char *insn)
{
    if (strstr(insn, "NN")) {
        return 2;
    }
    if (strstr(insn, "D")) {
        if (strstr(insn, "N")) {
            return 2;
        } else {
            return 1;
        }
    }
    if (strstr(insn, "N")) {
        return 1;
    }
    if (strstr(insn, "R")) {
        return 1;
    }
    return 0;
}

/* Get information about a Z-80 instruction */
static const char *get_insn_info(const unsigned char *data, size_t *op_size, size_t *size)
{
    const char *insn;
    unsigned char opcode;
    size_t opcode_size = 1;
    opcode = data[0];
    insn = opcodes_main[opcode];
    if (!insn) {
        if (opcode == 0xCB) {
            ++opcode_size;
            insn = opcodes_cb[data[1]];
        } else if (opcode == 0xDD) {
            ++opcode_size;
            insn = opcodes_dd[data[1]];
            if (!insn && data[1] == 0xCB) {
                ++opcode_size;
                insn = opcodes_ddcb[data[1]];
            }
        } else if (opcode == 0xFD) {
            ++opcode_size;
            insn = opcodes_fd[data[1]];
            if (!insn && data[1] == 0xCB) {
                ++opcode_size;
                insn = opcodes_fdcb[data[1]];
            }
        } else if (opcode == 0xED) {
            ++opcode_size;
            insn = opcodes_ed[data[1]];
        }
    }
    *op_size = opcode_size;
    if (insn) {
        *size = opcode_size + operand_size(insn);
        return insn;
    } else {
        *size = 1;
        return 0;
    }
}

/* Dump a Z80 instruction */
static void dump_instruction(FILE *out, unsigned address, const char *insn, const unsigned char *data)
{
    size_t count = 0;
    char ch;
    while ((ch = *insn++) != '\0') {
        if (ch == ' ') {
            while (count < 5) {
                fputc(' ', out);
                ++count;
            }
        } else if (ch == 'N' && insn[0] == 'N') {
            fprintf(out, "$%02X%02X", data[1], data[0]);
            data += 2;
            ++insn;
        } else if (ch == 'N') {
            fprintf(out, "$%02X", data[0]);
            data += 1;
        } else if (ch == 'D') {
            int value = (signed char)(data[0]);
            if (value > 0) {
                fprintf(out, "+$%02X", value);
            } else if (value < 0) {
                fprintf(out, "-$%02X", -value);
            }
            data += 1;
        } else if (ch == 'R') {
            fprintf(out, "$%04X", address + (int)(signed char)(data[0]));
            data += 1;
        } else if (ch >= 'a' && ch <= 'z') {
            fputc(ch - 'a' + 'A', out);
        } else {
            fputc(ch, out);
        }
        ++count;
    }
}

/* Map a ROM address to the name of the function that is being called */
static const char *map_rom_routine(unsigned address)
{
    switch (address) {
    case 0x0000: return "Reset Vector";
    case 0x0008: return "RST $08";
    case 0x0010: return "RST $10";
    case 0x0018: return "RST $18";
    case 0x0020: return "RST $20";
    case 0x0028: return "RST $28";
    case 0x0030: return "RST $30";
    case 0x0038: return "RST $38 - Interrupt Vector";
    case 0x0049: return "Keyboard Get";
    case 0x0050: return "Screen Get Character";
    case 0x01C9: return "Clear Screen";
    case 0x033A: return "Character Output";
    case 0x058D: return "Print Character";
    case 0x05C4: return "Check Printer Status";
    case 0x06A0: return "Enable Interrupts and Enter BASIC";
    case 0x1A19: return "Enter BASIC";
    case 0x1C90: return "Compare HL and DE";
    case 0x1C96: return "Examine String";
    case 0x1D78: return "Check Next Character";
    case 0x28A7: return "String Output";
    case 0x2EB8: return "Interrupt Handler";
    case 0x2EF4: return "Keyboard Scan";
    case 0x2EFD: return "Keyboard Scan Once";
    case 0x308B: return "Character Output 2";
    case 0x3450: return "Beep";
    case 0x345C: return "Sound Output";
    case 0x3AE2: return "Print CRLF";
    }
    return NULL;
}

/* Gets a BASIC token name from an address */
static const char *get_token_from_address(unsigned address)
{
    int token;
    if (token_handler[0] == 0) {
        return NULL;
    }
    for (token = 128; token < 256; ++token) {
        if (address == token_handler[token - 128]) {
            return basic_token_names[token - 128];
        }
    }
    return NULL;
}

/* Disassemble a block of Z80 instructions */
static void disassemble(FILE *out, unsigned address, const unsigned char *data, size_t len)
{
    const char *insn;
    size_t size, index;
    size_t opcode_size;
    const char *name;
    int prev_was_jump = 0;
    while (len > 0) {
        name = map_rom_routine(address);
        if (!name) {
            name = get_token_from_address(address);
        }
        if (name) {
            printf(";\n");
            printf("; %s\n", name);
            printf(";\n");
        } else if (prev_was_jump) {
            printf(";\n");
        }
        prev_was_jump = 0;
        fprintf(out, "%04X:", address);
        insn = get_insn_info(data, &opcode_size, &size);
        for (index = 0; index < size; ++index) {
            fprintf(out, " %02X", data[index]);
        }
        while (index < 4) {
            fprintf(out, "   ");
            ++index;
        }
        fprintf(out, "     ");
        if ((data[0] == 0xCD || data[0] == 0xC3) && data[2] < 0x40) {
            /* Probably a call into a ROM routine.  Is it one we recognize? */
            unsigned dest = data[1] + (((unsigned)(data[2])) << 8);
            name = map_rom_routine(dest);
            if (!name) {
                name = get_token_from_address(dest);
            }
            dump_instruction(out, address + size, insn, data + opcode_size);
            if (name) {
                fprintf(out, "            ; %s", name);
            }
        } else if (insn && insn[0] != '\0') {
            dump_instruction(out, address + size, insn, data + opcode_size);
        } else {
            fprintf(out, "DB   $%02X", data[0]);
        }
        if (data[0] == 0x18 || data[0] == 0xC3 || data[0] == 0xC9 || data[0] == 0xE9) {
            /* Unconditional jump instruction: "JR", "JP", "RET", or "JP (HL)" */
            prev_was_jump = 1;
        }
        fprintf(out, "\n");
        if (size >= len) {
            break;
        }
        address += size;
        len -= size;
        data += size;
    }
}
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

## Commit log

2023-12-29 Recreate the VZ200 schematic in Kicad
    [VZ200.kicad_pcb, VZ200.kicad_sch, address_decoding.kicad_sch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]
2023-12-29 Schematic for the VZ200 printer interface
    [VZ200.kicad_sch, VZ200_Printer_Interface.kicad_pcb, VZ200_Printer_Interface.kicad_sch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]
2023-12-29 16K Memory Expansion Cartridge for VZ200
    [VZ200_16K_RAM_Expansion.kicad_pcb, VZ200_16K_RAM_Expansion.kicad_sch, dynamic_ram.kicad_sch]
2023-12-29 Mention that the 6K of Program RAM is on a separate PCB
    [program_ram.kicad_sch]
2023-12-31 Custom RAM/ROM expansion board concept
    [RAM_ROM_Expansion.kicad_pcb, RAM_ROM_Expansion.kicad_sch]
2023-12-31 Add title and revision details to the schematic sheets
    [RAM_ROM_Expansion.kicad_sch, VZ200.kicad_sch, VZ200_16K_RAM_Expansion.kicad_sch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]
2024-01-05 Update motherboard schematic based on inspection of the actual board
    [VZ200.kicad_sch, address_decoding.kicad_sch, expansion_ports.kicad_sch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]
2024-01-17 Restoration Part 2
    [VZ200.kicad_sch, address_decoding.kicad_sch]
2024-01-23 VZ200/VZ300 Joystick Interface Schematic
    [VZ200_Joystick_Interface.kicad_pcb, VZ200_Joystick_Interface.kicad_sch]
2024-01-24 Update part numbers for the joystick interface
    [VZ200_Joystick_Interface.kicad_sch]
2024-01-24 Updates on recently acquired gear
2024-01-25 D.Newcombe's Custom 32K RAM Expansion Module
    [D_Newcombe_32K_RAM_Expansion.kicad_pcb, D_Newcombe_32K_RAM_Expansion.kicad_sch]
2024-04-05 Fix opcodes for "push ix" and "push iy"
    [vzdasm.c]
2024-04-30 VZ300 schematic in KiCad
    [VZ300.kicad_pcb, VZ300.kicad_sch, expansion_ports.kicad_sch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]
2024-04-30 Fix some minor issues in the VZ300 schematic
    [gate arrays.kicad_sch, video_controller.kicad_sch]
2024-05-15 Document the placement of DRAM chips in the VZ300 schematic
    [program_ram.kicad_sch]
2025-02-03 Fix a bug in the dead test on devices with 34K of RAM
